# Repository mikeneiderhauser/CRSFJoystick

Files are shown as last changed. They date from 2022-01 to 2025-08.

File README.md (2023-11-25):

# ELRSJoystick / CRSFJoystick

<https://github.com/mikeneiderhauser/CRSFJoystick>

Named CRSFJoystick as it indicates the wire protocol between the microcontroller (pi pico) and receiver).

Arduino code using the mbed core that runs on a Pi Pico (2040) to emulate a USB HID Joystick

Pirmarily developed to use and ExpressLRS receiver and a HID Joystick for Sim use! It will work with both Tracer and Crossfire as well.

Shout out to CapnBry for the Crsf Library

https://github.com/CapnBry/CRServoF

Shout out to RealRobots.net for the Gamepad Library

https://gitlab.com/realrobots/PicoGamepad/-/tree/master

# Future Plans

- GitHub Builds
- Rework HID USB code
- Add failsafe nopulses / hold

# Demo Video
ELRS HID Joystick Demo (https://www.youtube.com/watch?v=MCOWKvFTHRc)

## Purchase

Originally offered of FPVExchange, but that is no longer an option. Please send me an email for availability, purchase, or to get additional info!

<housefpv@gmail.com>

You can also contact me on discord [HouseFPV](https://discordapp.com/users/HouseFPV#5899)

- Blank carrier boards for Pi Pico, Tiny 2040, and Waveshare RP2040 (old stock)
- Built and flashed units
- [DIY Section](#diy-hardware)

A few boards that I believe are based off of this project:
- HGLRC Dongle (I have samples from HGLRC on the way)
  - [HGLRC Dongle at HGLRC](https://www.hglrc.com/collections/new-arrivals/products/hglrc-c1-remote-control)
  - [HGLRC C1 Radio Kit with dongle at HGLRC](https://www.hglrc.com/collections/new-arrivals/products/hglrc-c1-remote-control)
  - [HGLRC C1 Radio Kit with dongle at RacedayQuads](https://www.racedayquads.com/products/hglrc-c1-transmitter-elrs-2-4ghz-choose-your-version?keyword=hglrc%20c1)
- Squid Stick (I have personally not tested one)
  -  [Squid Stick at Progressiverc.com](https://www.progressiverc.com/products/squid-stick-elrs-2-4ghz-usb-receiver-module)
  -  Squid Stick at RacedayQuads - Link to be posted when available
- YMZFPV Simulator Adapter (have not yet been able to confirm that this is based off of this project)
  - [YMZFPV Sim Adapter at RacedayQuads](https://www.racedayquads.com/products/ymzfpv-wireless-simulator-adapter-for-sbus-pwm-csfr-choose-your-version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)

## Compatability

This project was designed primarily with ELRS usage in mind, however this code base has also been tested with TBS Crossfire Receivers (915MHZ) (last tested v6.16) and TBS Tracer Receivers (2.4GHz) (last tested v6.17) and both appear to work! Flight was teseted in the Liftoff simulator.

I no longer have TBS Crossfire nor TBS Tracer TX modules or Receivers so future tests will have to be conducted by others.

### ExpressLRS (Waveshare RP2040)
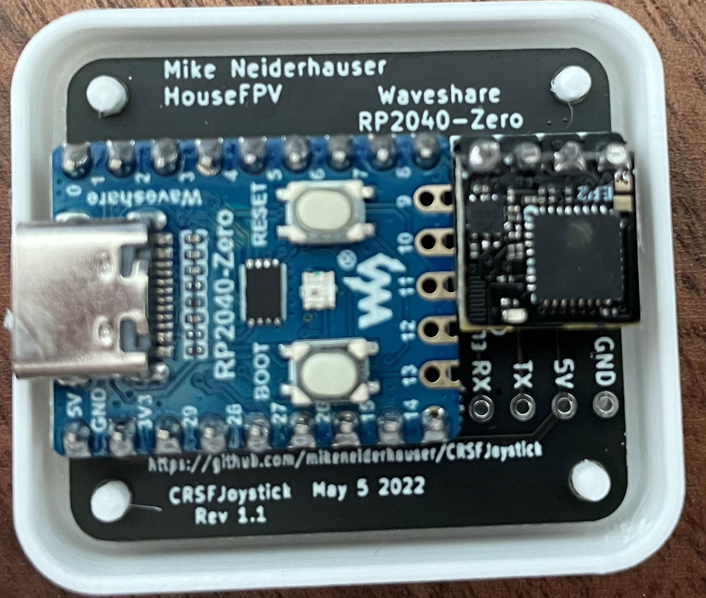
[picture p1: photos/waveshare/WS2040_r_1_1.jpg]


### Crossfire



### Tracer


# Building / Flashing

I recently converted the projet to PlatformIO to aid in building, board management, etc.  PlatformIO has some known quirks with PiPico boards and I'm going to leave some breadcrumbs here for later.

## VSCode with PlatformIO

### Installing VSCode and PlatformIO
<https://platformio.org/install/ide?install=vscode>

### Build for specific board / environment

At the Bottom of VSCode you will see a tool bar.  Look for `Default (CRSFJoystick)`.  Building in this state will build for all boards / environments defined in the `platformio.ini` file.  To target a sepecific board, Click on `Default (CRSFJoystick)` and select an appropriate option (Note, selection pops up at the top of vscode).



Click on the Checkmark on the bottom toolbar to build for the board / environment you selected.

Click on the `->` on the bottom toolbar to upload to the board.  If upload fails to find your board, please see bothe the [alternative upload](#alternative-upload) section as well as the driver section.

## Alternative upload
This is one of the standard advertised methods for uploading firmware to a pipico based microcontroller board.

Press and hold the bootsel button on your board and either plugin/power on the board or if the board is already powered press and release the reset button.

This will put the board in RP2 Boot mode.

A removable device should pop up or become available on your computer.  Drag and drop the `firmware.u2f` file from the `.pio/build/wavesharerp2040zero/` directory into this device on your computer.  Note replpace wavesharerp2040zero with the environment for your board.

## Drivers
Drivers can be hit or miss for the pipico board and platformio.  

You may need to use zadig to get vscode+platforio to be able to upload directly to the board.
<https://github.com/platformio/platform-raspberrypi/issues/2#issuecomment-828586398>

Below are the drivers I have working on my Windows 11 machine.  You may need to modify the driver selection via zadig and or device manager to get it working.

- Standard Running Mode
  - RaspberryPi Pico (Interface 0)
    - Zadig -> HidUsb v10.0.22621.819
    - Device Manager -> Human Interface Devices -> HID-compliant game controller
  - RaspberryPi Pico (Interface 1)
      - Zadig -> usbser v10.0.22621.1778
      - Device Manager -> Ports (COM & LPT) -> USB Serial Device
- RP2 Boot mode
  - RP2 Boot (Interface 0) 
    - Zadig USBSTOR v10.0.022621.1778 
    - Device Manager -> Disk Drives -> RPI RP2 USB Device 
  - RP2 Boot (Interface 1)
    - Zadig WinUSB v6.1.7600.16385
    Device Manager -> Universal Serial Bus Devices -> RP2 Boot

### Device manager clicks to change driver 
Right Click -> Properties -> Update Driver -> Browse my computer for drivers -> Let me pick from a list of available drivers on my computer

# Flashing ELRS Receiver

Depending on the device you are using, your target may be different.  For all of the DIY version's I've made, I used the HappyModel EP2 Rx.  Other vendors may vary.

## Flashing via Betaflight Passthrough
<https://www.expresslrs.org/software/updating/betaflight-passthrough/>

## Flashing via Wifi
If your receiver is wifi enabled you can also flash it via wifi

<https://www.expresslrs.org/software/updating/wifi-updating/>

# Testing
For a quick test of functionality, I typically go to [GamepadTester](https://hardwaretester.com/gamepad).

Once the Radio is bound to the RX, it should show up in GamePadTester.

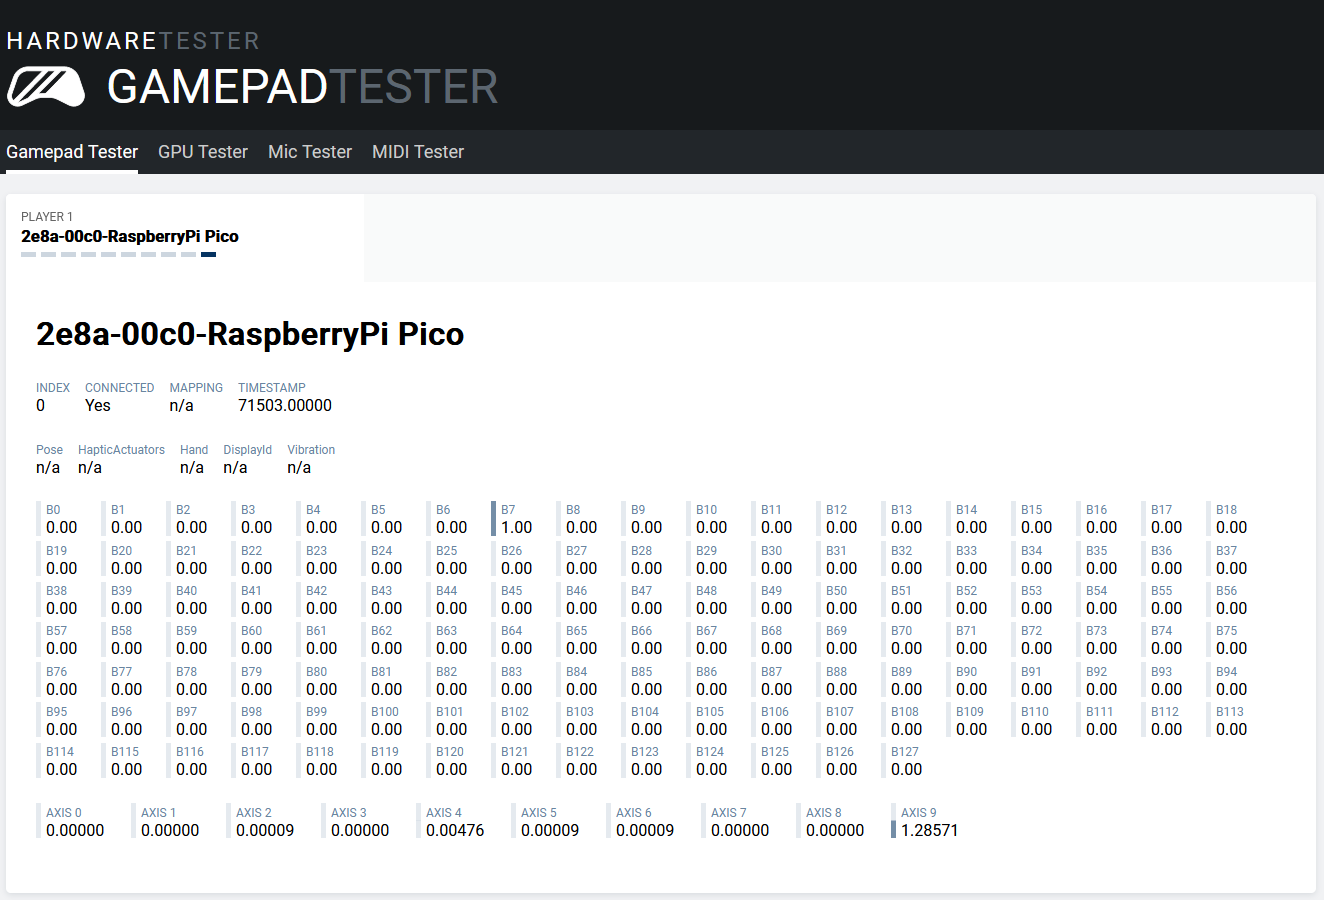
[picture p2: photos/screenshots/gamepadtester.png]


# Mappings
This was a quick map and is not fully featured.

On link up/down the onboard Pi Pico LED will light indicating connection

*NOTE* Channel 5, 6, 7, and 8 are mapped both to analog axis as well as joystick buttons.

| Channel | Logical Mapping  | Joystick Mapping |
| --- | --- | --- |
| 1 | A | X |
| 2 | E | Y |
| 3 | T | Rx |
| 4 | R | Ry |
| 5 | Channel 5 (Full) AND AUX1 (1510-2011) | Z  AND Button 0 |
| 6 | Channel 6 (Full) AND AUX2 (1510-2011) | Rz AND Button 1 |
| 7 | Channel 7 (Full) AND AUX3 (1510-2011) | S0 AND Button 2 |
| 8 | Channel 8 (Full) AND AUX4 (1510-2001) | S1 AND Button 3 |
| 9 | AUX5 (1510-2011) | Button 4 |
| 10 | AUX6 (1510-2011) | Button 5 |
| 11 | AUX7 (1510-2011) | Button 6 |
| 12 | AUX8 (1510-2011) | Button 7 |
| 13 | Not Used | Not Used |
| 14 | Not Used | Not Used |
| 15 | LQ - Not Used | Not Used |
| 16 | RSSI - Not Used  | Not Used |

*Note additional button mappings can be created in caliration.h*

# Here below is for DIY Builds and may be slightly outdated
# DIY Hardware

In a nutshell, wire the ELRS RX up to a uart on the pipico, 5v, and gnd.

| Raspberry Pico | ELRS/CRSF Receiver |
| --- | --- |
| VBUS (PIN 40)  | 5V |
| GND  (PIN 38)  | GND
| GP4  (PIN 6) | RX |
| GP5  (PIN 7) | TX |

Other boards are supported, see the [board_defs.h](./include/board_defs.h) file.

| Part  | Link | Approx Cost |
| ----- | ---- | ---|
| Pi Pico | https://www.pishop.us/product/raspberry-pi-pico/ | $4 (Approx $6 with shipping) |
| Waveshare RP2040 zero | https://www.amazon.com/RP2040-Zero-Development-Microcontroller-Multi-Function-Integration/dp/B09SBCKYSC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| $10|
| Tiny 2040 (alt part) | https://www.pishop.us/product/tiny-2040/ | $10 (Approx $12 with shipping) |
| ELRS RX (any will do) |  https://www.racedayquads.com/products/happymodel-2-4ghz-ep2-tcxo-rx-express-lrs-receiver?keyword=expresslrs | $18 |

Note, price breaks can be had when purchasing at quantity.

Approx part cost for pico hardware (large footprint, cheaper) - $20-$25

- Pi Pico - $4.00
- ELRS RX - $13.50 
- Carrier Board - $1.00 (approx)
- Shipping / Tax from vendors - varies

# Carrier Boards

## ELRSJoystick

This board has an ELRS RX built in, so you don't need to wire any RX on, just plug in and connect to your ELRS TX, then you are ready to go!

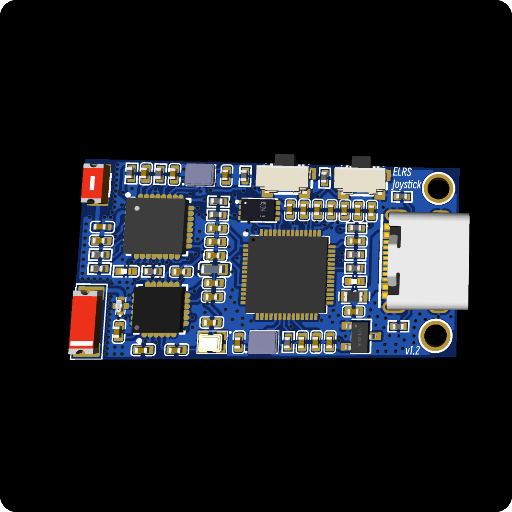
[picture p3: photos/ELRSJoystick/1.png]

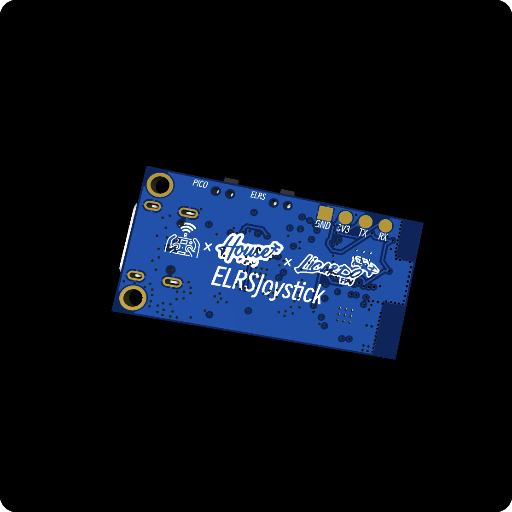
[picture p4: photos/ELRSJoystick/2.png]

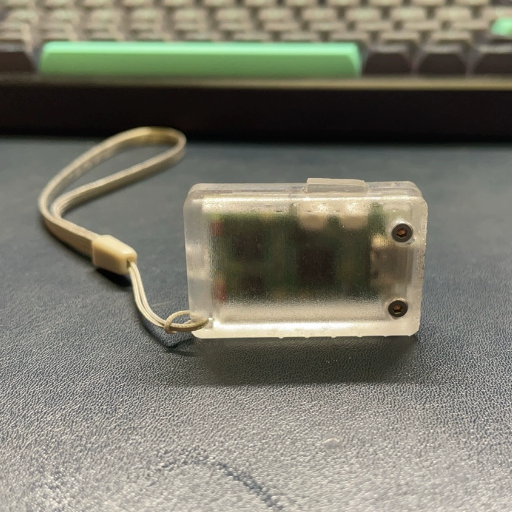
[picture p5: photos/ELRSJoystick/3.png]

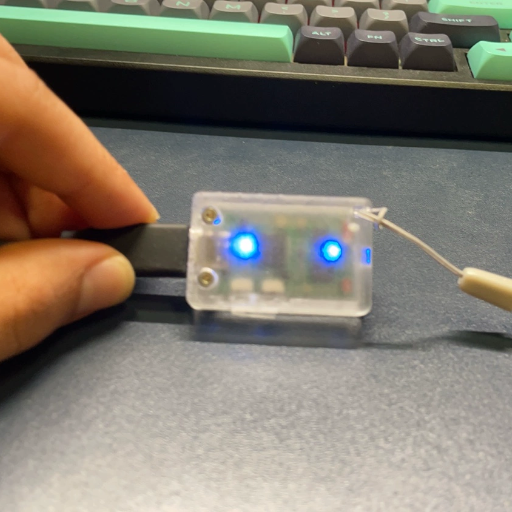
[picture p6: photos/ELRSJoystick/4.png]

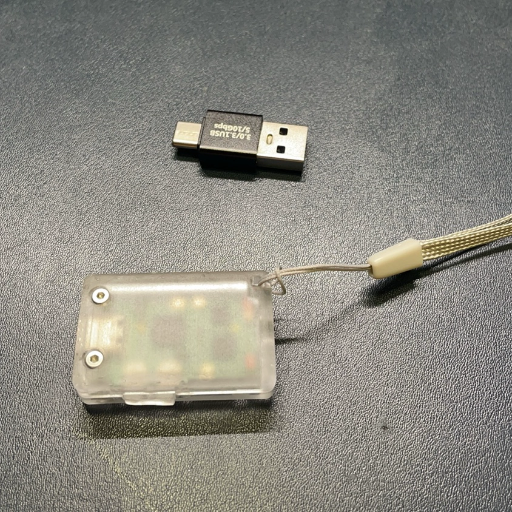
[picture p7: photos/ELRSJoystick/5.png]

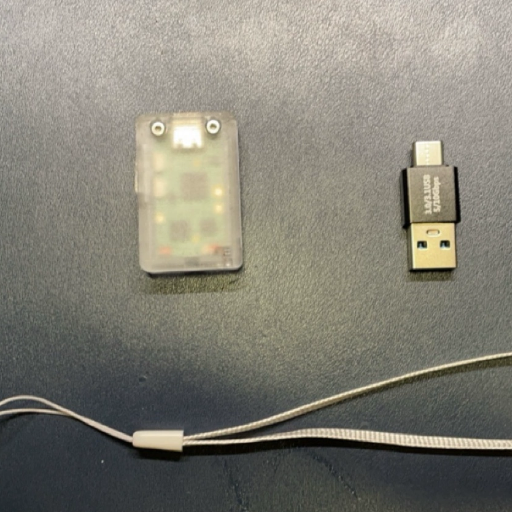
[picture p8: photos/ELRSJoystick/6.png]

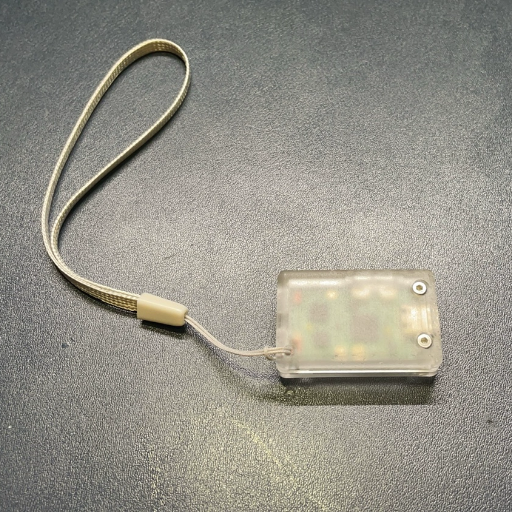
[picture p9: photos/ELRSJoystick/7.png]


## Tiny Version

> **_NOTE:_** References to level shifters below are no longer needed as the level shifter can be omitted. You will have to bridge the pads on the level shifter for the TX/RX pins or use a newer version of the carrier board.

I personally use the Waveshare RP2040-Zero version for my ELRS Joystick!

Hardware build files are located in hardware/kicad/CRSFJoystick/output/Rev1.0

I used JLCPCB with Black Soldermask and a board thickness of 1.6mm.

R1.0 Build Photo

Note the different orientation of the ELRS RX's.  The orientation can be flipped.  I installed each RX to ensure the boot pad is exposed should the RX need recovered.

## Waveshare RP2040-Zero

[WaveShare RP2040-Zero Board](https://www.waveshare.com/rp2040-zero.htm)

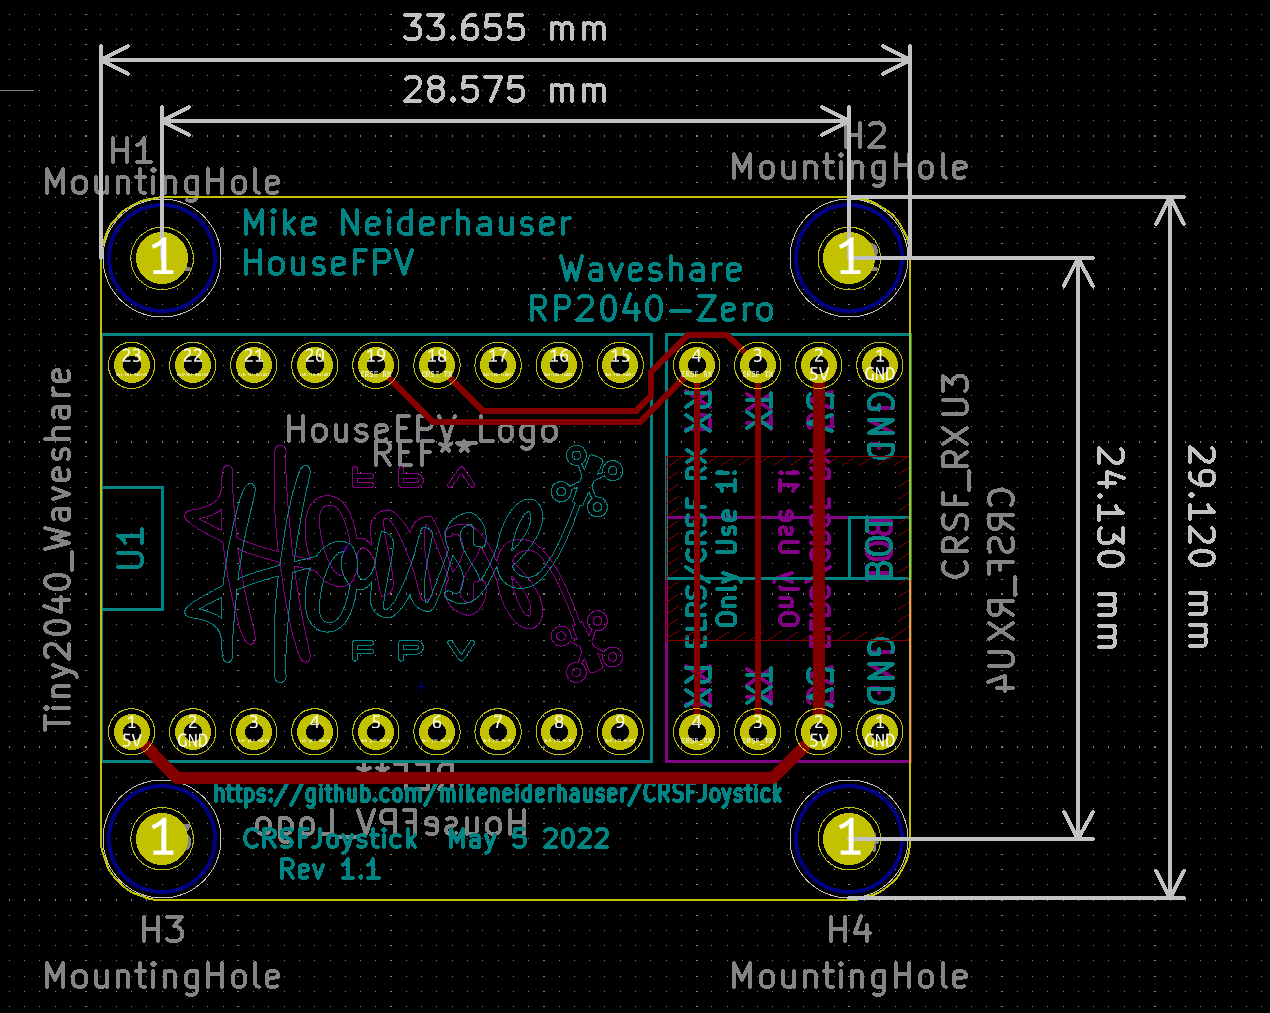
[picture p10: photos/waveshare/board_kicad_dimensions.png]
WaveShare RP2040-Zero BoardDimensions


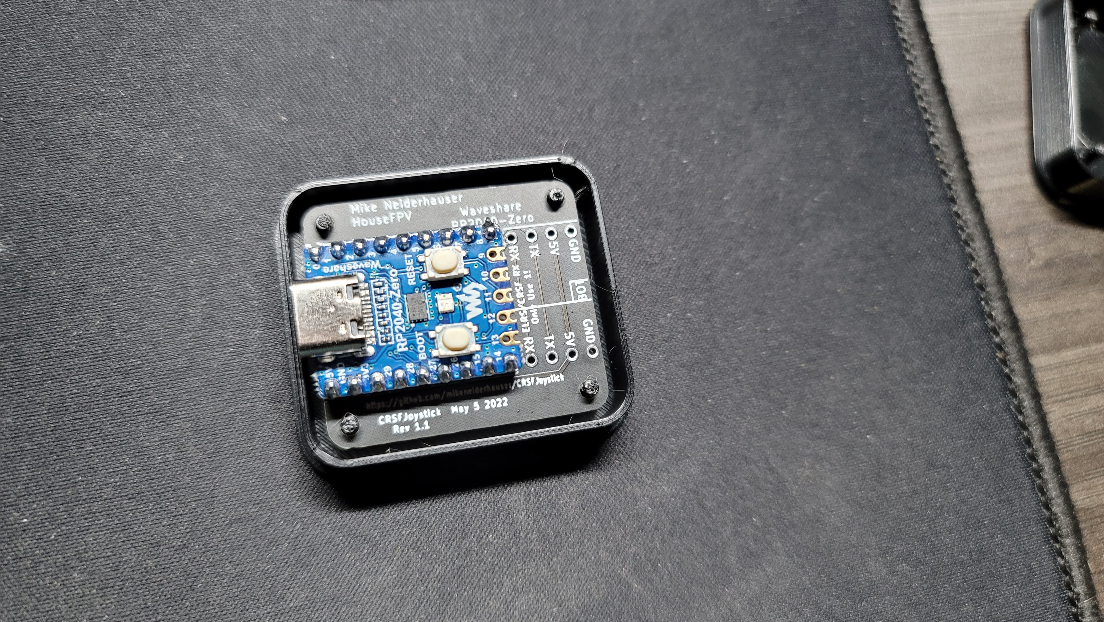
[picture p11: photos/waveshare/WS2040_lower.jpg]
WaveShare RP2040 Case lower


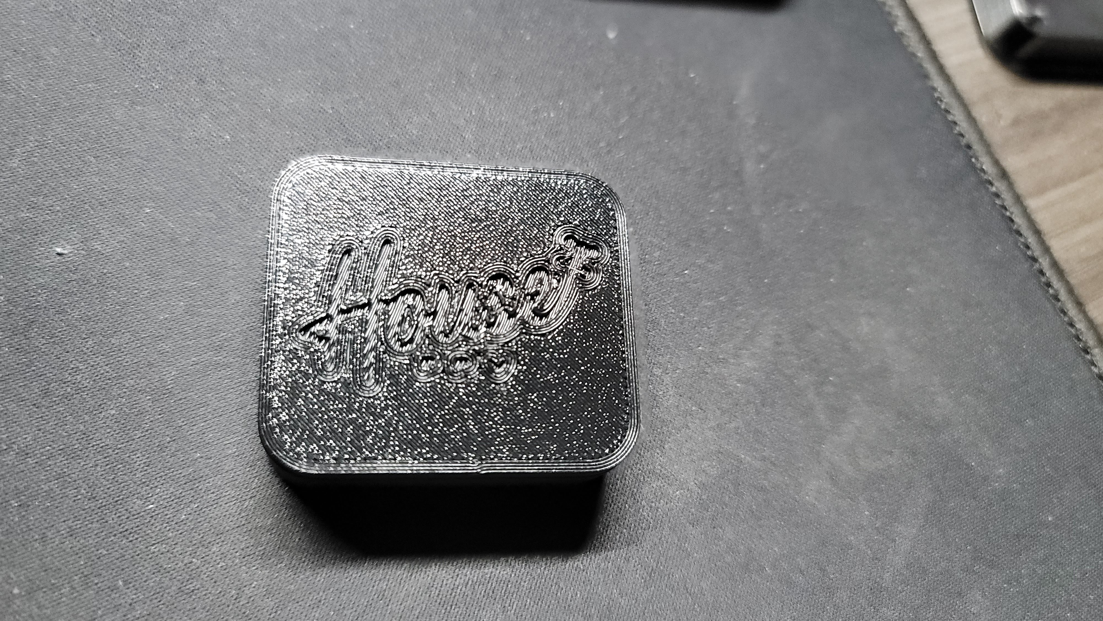
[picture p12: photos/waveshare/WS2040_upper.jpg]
WaveShare RP2040 Case Upper


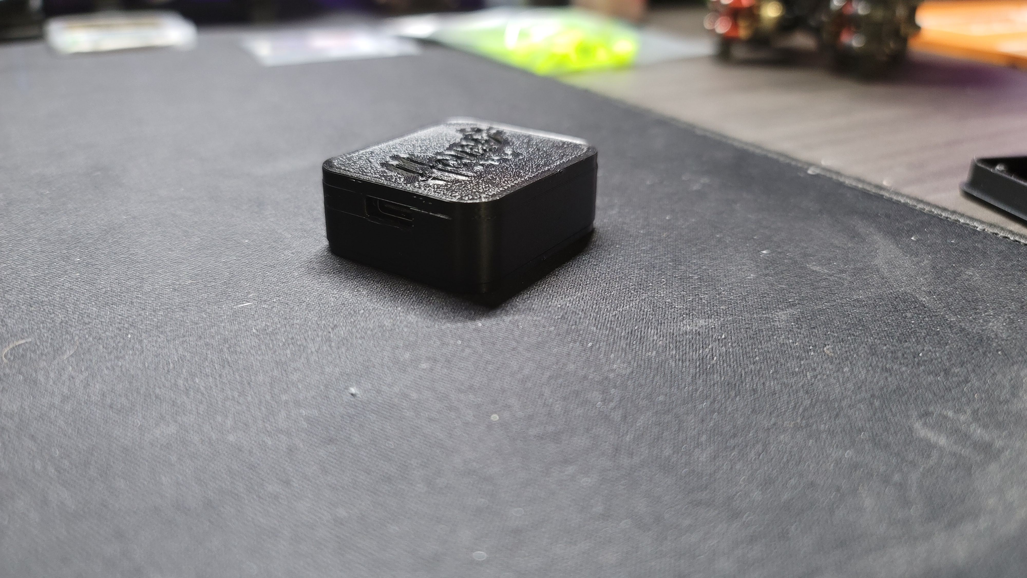
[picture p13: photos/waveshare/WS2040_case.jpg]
WaveShare RP2040 Case assembled


## Raspberry Pi Pico (Full Version)

Pico Build Front

Pico Build Back

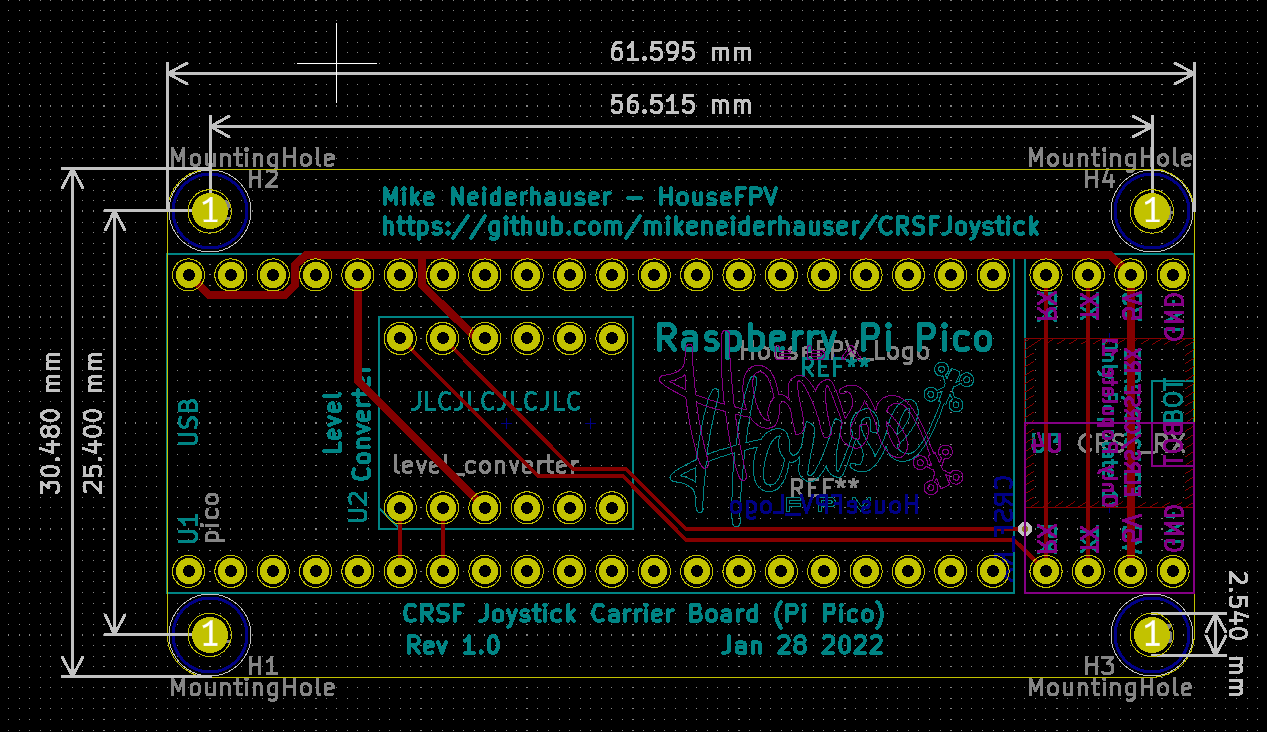
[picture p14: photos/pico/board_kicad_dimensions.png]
Pi Pico Dimensions


## Tiny2040

Tiny2040 Build Front

Tiny2040 Build Back

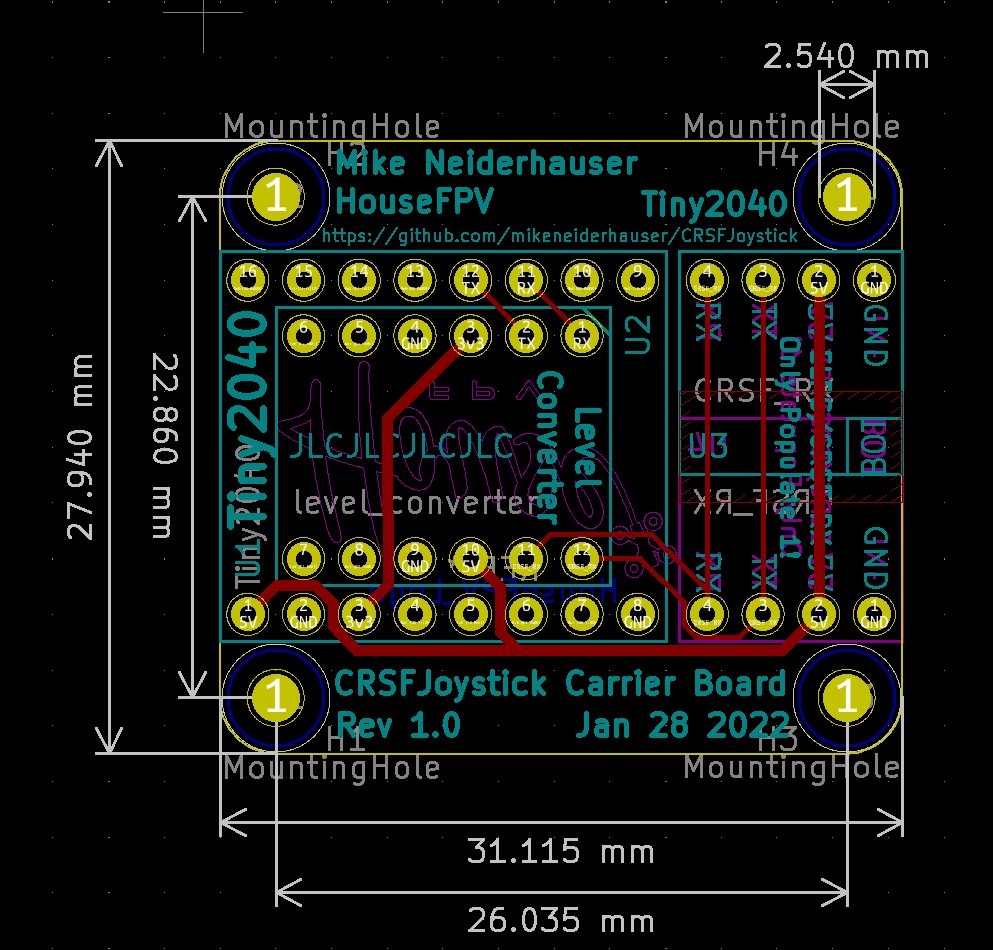
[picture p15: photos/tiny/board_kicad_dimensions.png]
Tiny2040 Dimensions


## SEEED AXIO 2040

Board files now in the hardware folder.  Not built or tested but should work.

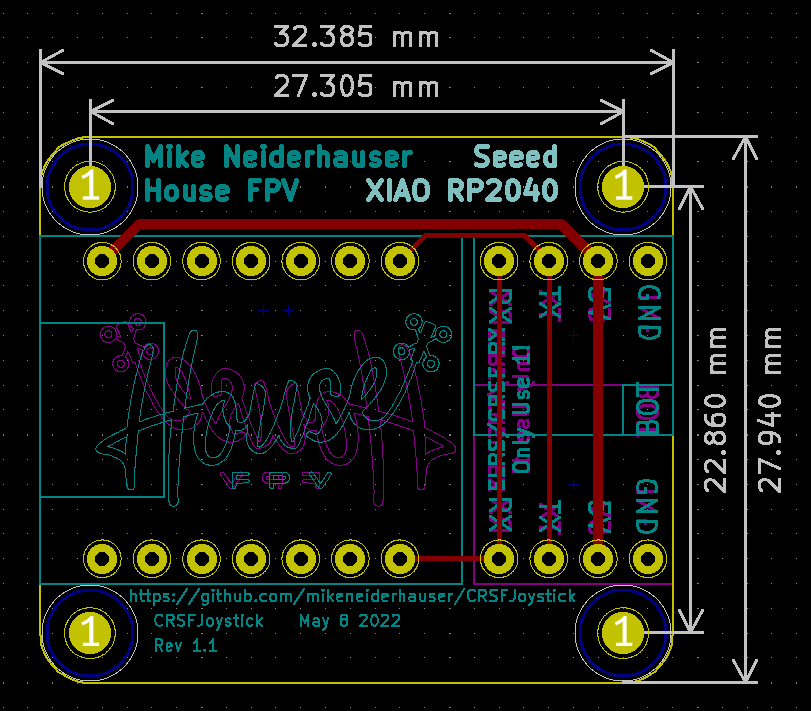
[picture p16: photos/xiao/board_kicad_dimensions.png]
SEEED XAIO RP2040 Dimensions


[SEEED XAIO RP2040 Board](https://www.seeedstudio.com/XIAO-RP2040-v1-0-p-5026.html)

## CRSFJoystick2.0

Build a smaller pico by yourself.

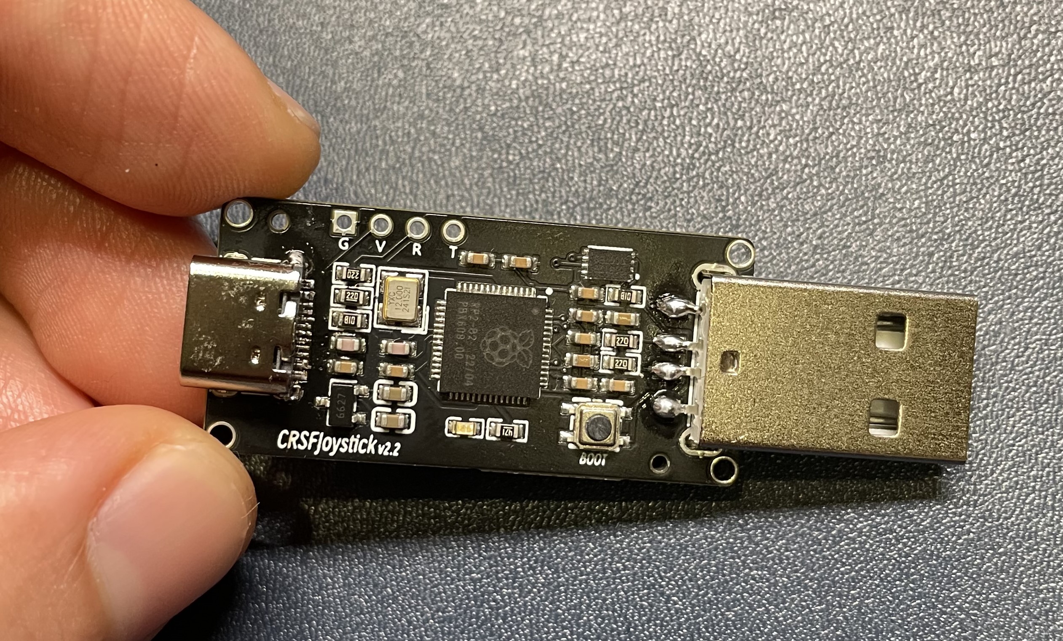
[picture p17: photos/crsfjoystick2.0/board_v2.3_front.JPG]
CRSFJoystick2.3 Board Front

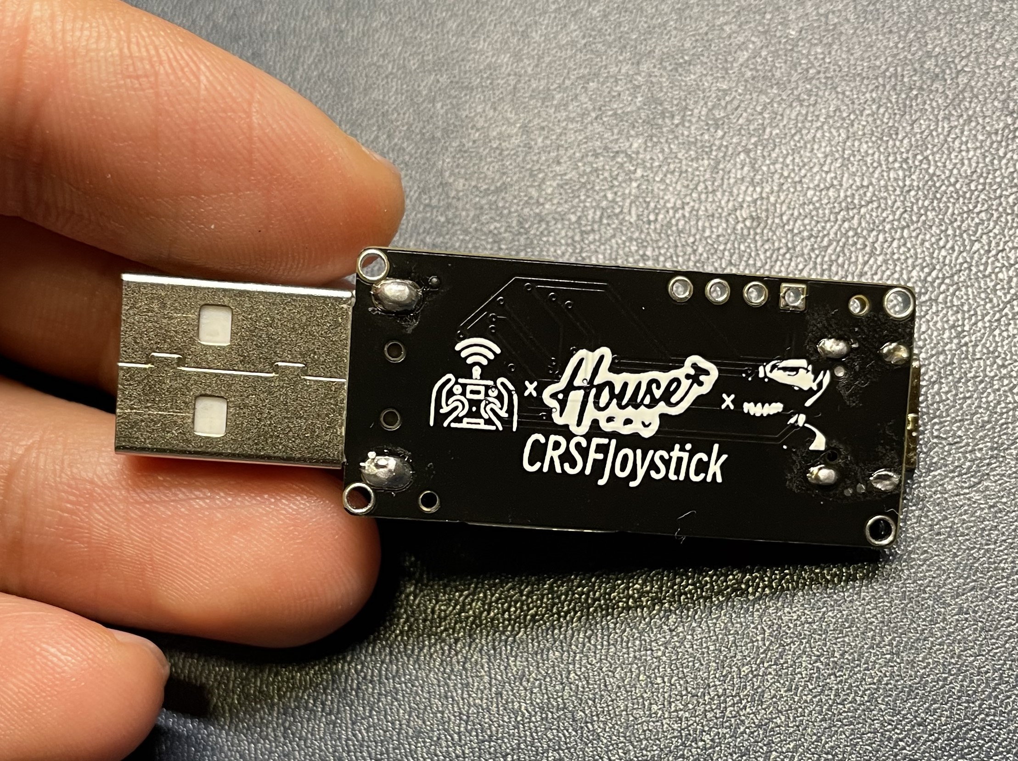
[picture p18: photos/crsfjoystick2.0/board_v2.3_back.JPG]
CRSFJoystick2.3 Board Back

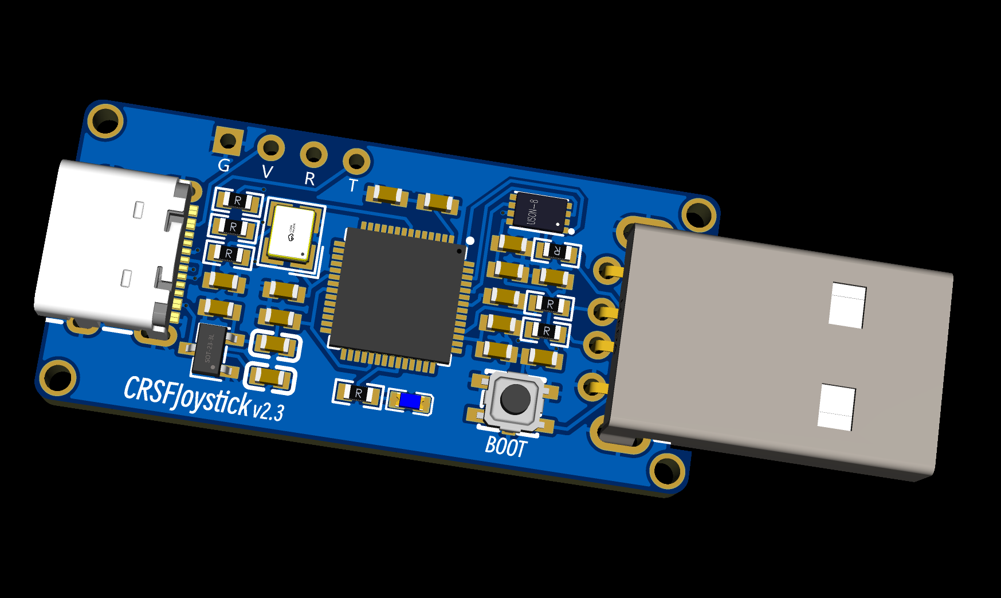
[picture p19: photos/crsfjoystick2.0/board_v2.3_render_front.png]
CRSFJoystick2.3 Render Front

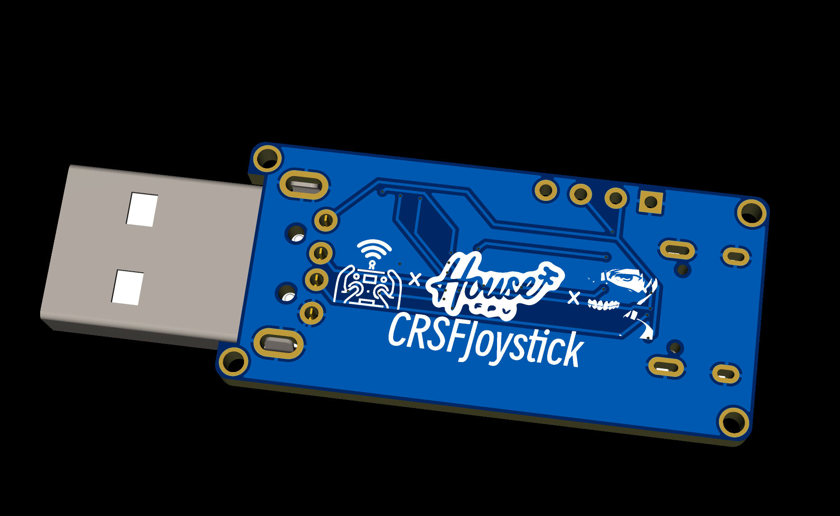
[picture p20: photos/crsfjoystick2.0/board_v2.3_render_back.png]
CRSFJoystick2.3 Render Back

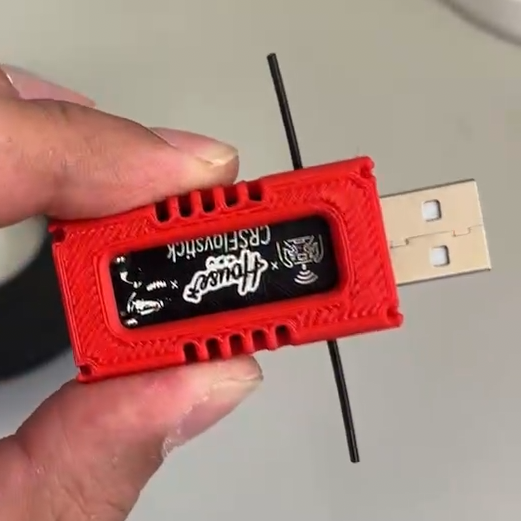
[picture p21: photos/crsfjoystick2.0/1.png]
CRSFJoystick2.3 Render Back

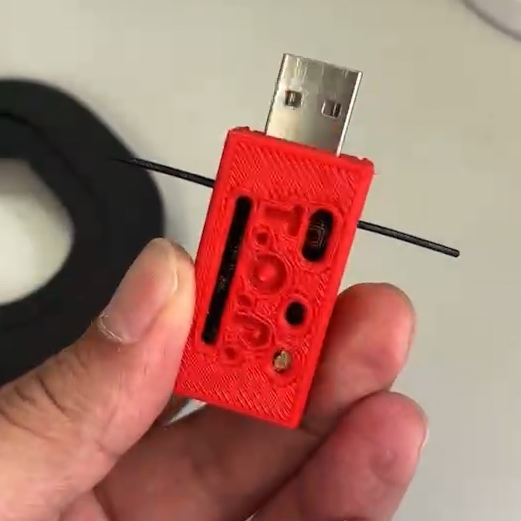
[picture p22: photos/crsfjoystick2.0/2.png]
CRSFJoystick2.3 Render Back

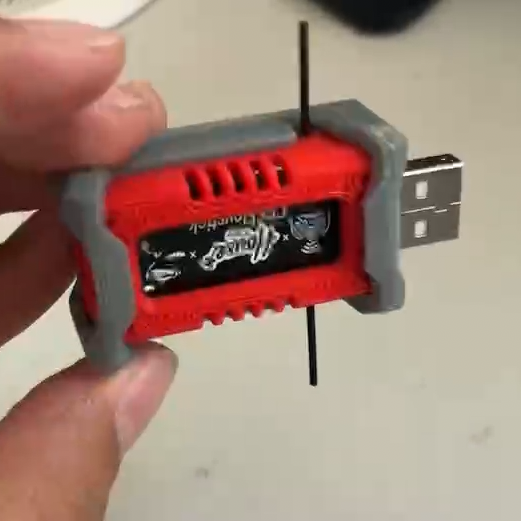
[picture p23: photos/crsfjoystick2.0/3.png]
CRSFJoystick2.3 Render Back

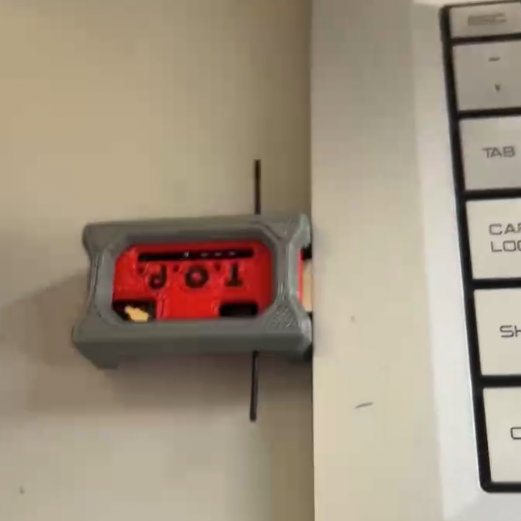
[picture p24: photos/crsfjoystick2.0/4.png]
CRSFJoystick2.3 Render Back

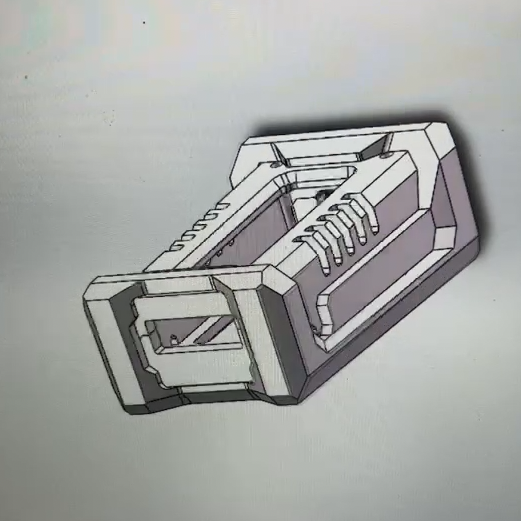
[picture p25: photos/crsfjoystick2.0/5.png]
CRSFJoystick2.3 Render Back

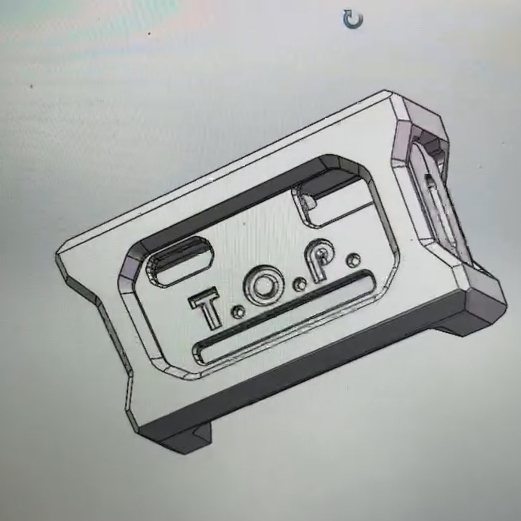
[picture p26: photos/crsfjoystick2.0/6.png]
CRSFJoystick2.3 Render Back

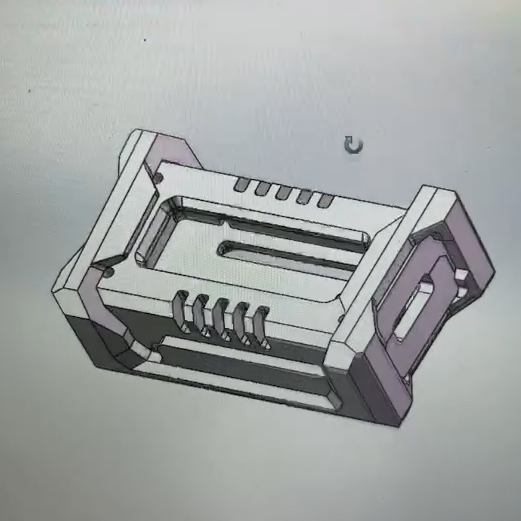
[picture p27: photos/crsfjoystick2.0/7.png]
CRSFJoystick2.3 Render Back


# General Assembly

- Print the top and bottom enclosure
- Print 2 of the spacers for the Pi2040, Print 4 of the spacers for the Pi Pico version
- Follow the directions in this video https://youtu.be/Zuhfbobgm5A

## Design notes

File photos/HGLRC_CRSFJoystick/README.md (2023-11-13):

Onboard 2.4GHz ELRS receiver, receiver firmware: HGLRC Hermes 2.4GHz RX.   
Reserve the expansion receiver pad and use the toggle switch to switch between the onboard or external receiver.   
The latest uploaded Gerber file adds the housefpv and ExpressLRS logos.

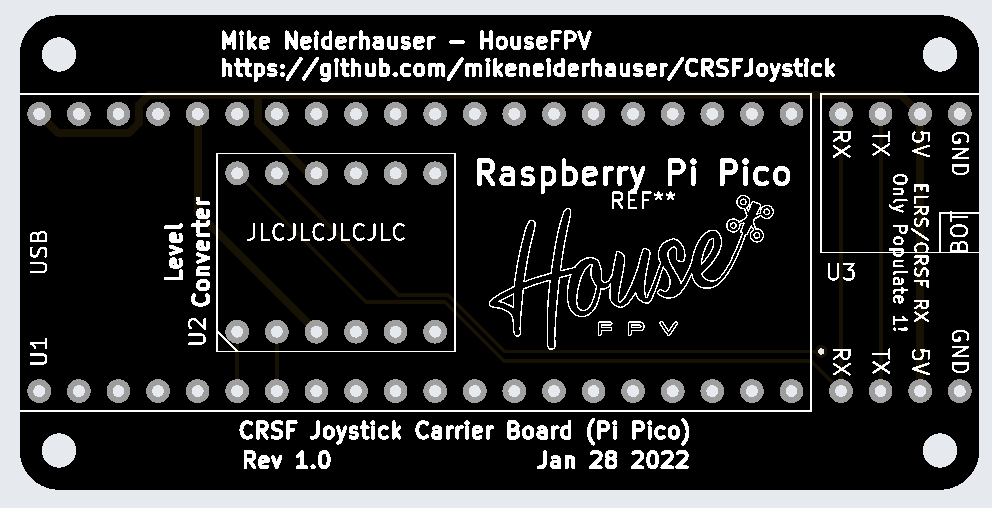
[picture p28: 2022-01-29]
photos/pico/board_render_front.png

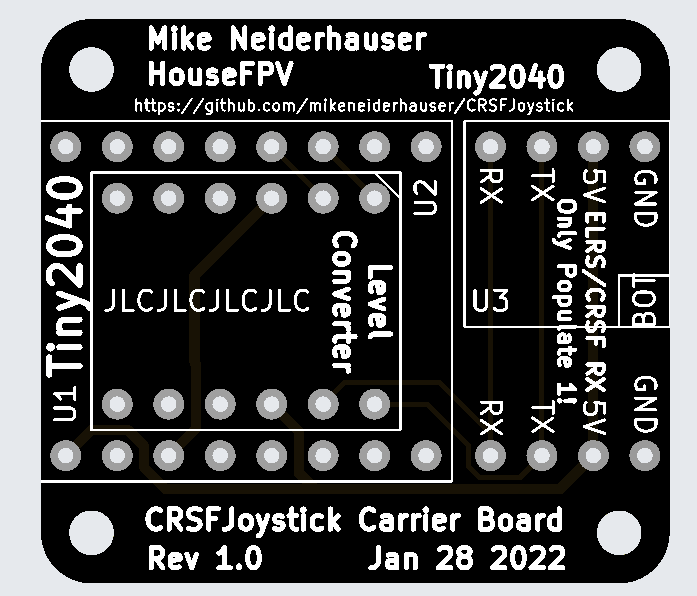
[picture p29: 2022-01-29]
photos/tiny/board_render_front.png

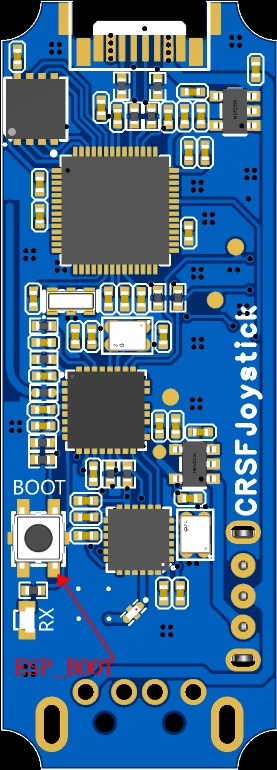
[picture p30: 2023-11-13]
photos/HGLRC_CRSFJoystick/board_render_back_V1.1.jpg

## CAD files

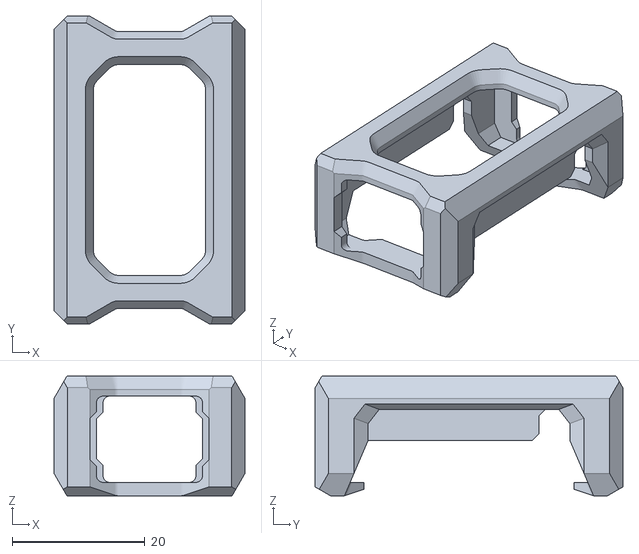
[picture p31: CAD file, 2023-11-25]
STL/CRSFJoystick/v2.3/Cover.STL
28.8 x 46.4 x 18.0

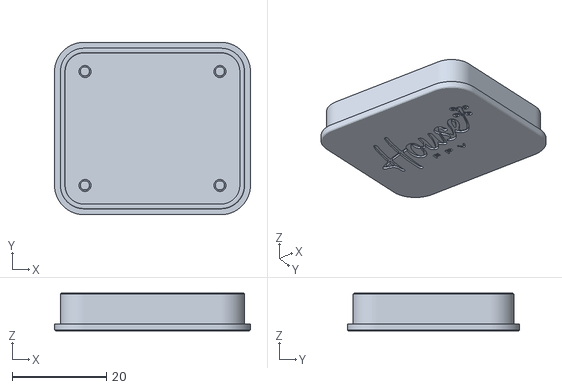
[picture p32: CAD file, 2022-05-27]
STL/CRSFJoystick/Waveshare_2040/Waveshare RP2040 Lower.stl
41.5 x 36.5 x 8.00

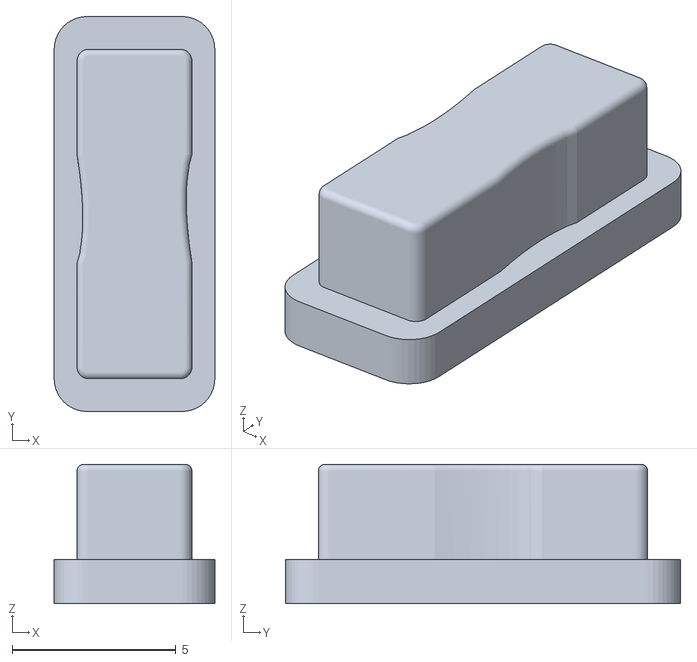
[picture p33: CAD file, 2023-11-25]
STL/ELRSJoystick/Licardo/Button.stl
4.90 x 12.0 x 4.25

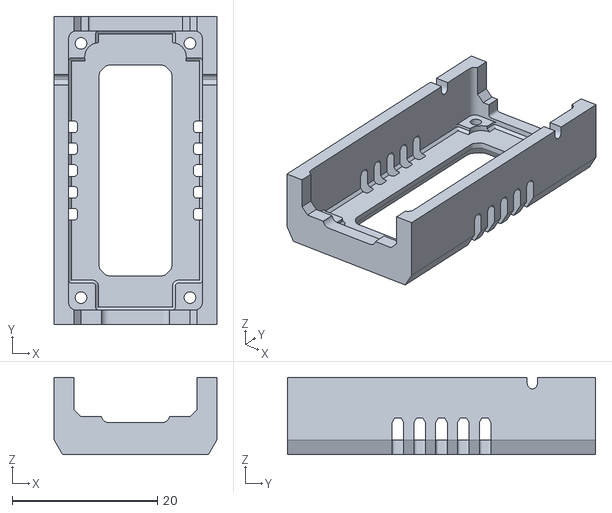
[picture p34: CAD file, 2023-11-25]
STL/CRSFJoystick/v2.3/Bottom.STL
22.4 x 42.4 x 10.6

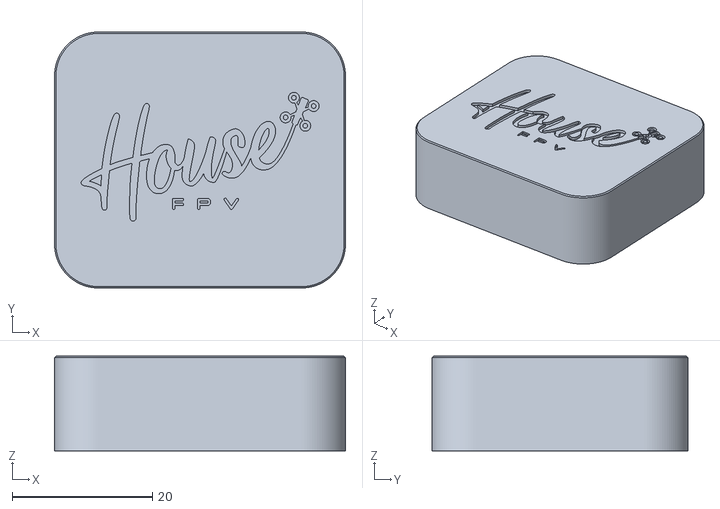
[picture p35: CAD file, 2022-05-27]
STL/CRSFJoystick/Waveshare_2040/Waveshare PR2040 top.stl
41.5 x 36.5 x 13.5

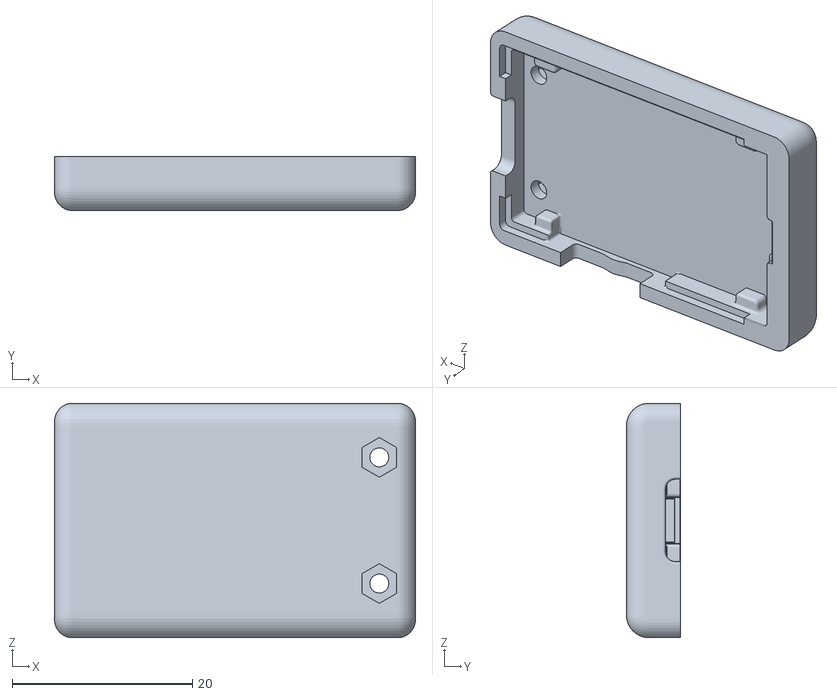
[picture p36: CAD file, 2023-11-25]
STL/ELRSJoystick/Licardo/Bottom.STL
40.0 x 6.00 x 26.0

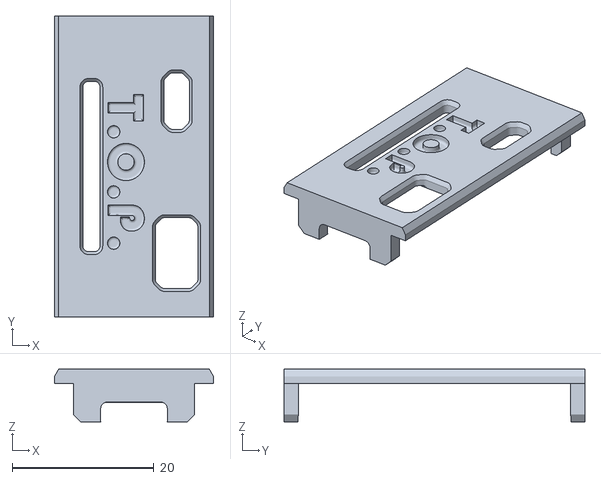
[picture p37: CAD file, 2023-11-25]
STL/CRSFJoystick/v2.3/Top.STL
22.4 x 42.4 x 7.40

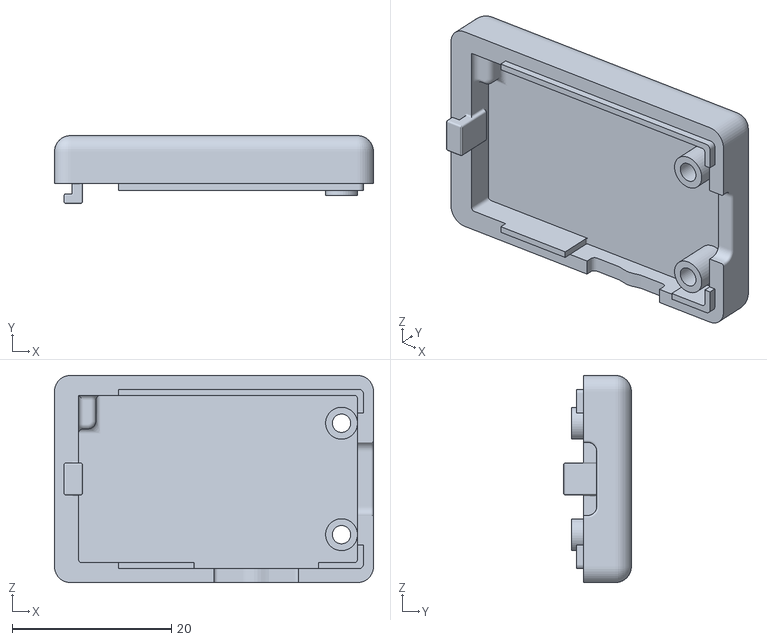
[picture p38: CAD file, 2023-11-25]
STL/ELRSJoystick/Licardo/Top.STL
40.0 x 8.50 x 26.0

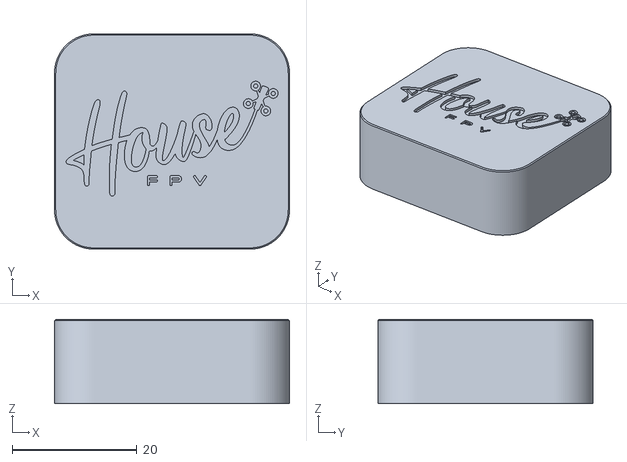
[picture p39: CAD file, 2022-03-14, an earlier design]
STL/CRSFJoystick/v1.0/top.stl
37.6 x 34.4 x 13.5

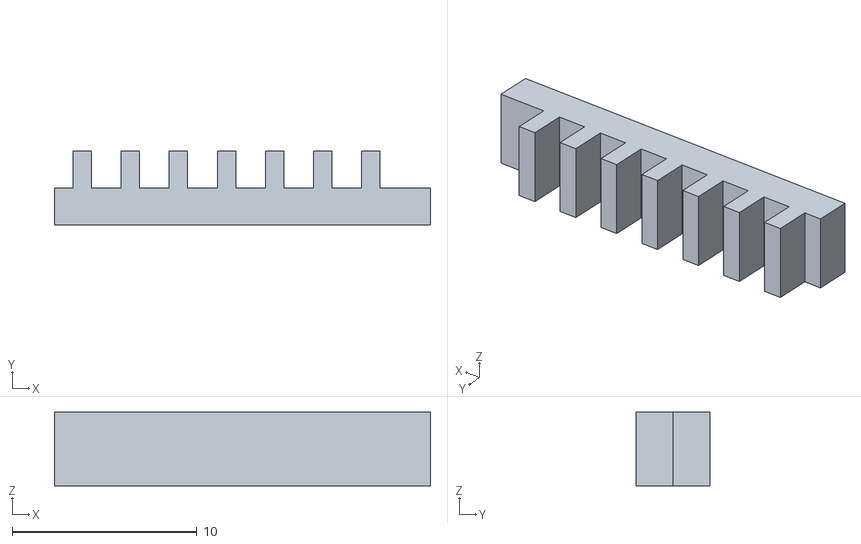
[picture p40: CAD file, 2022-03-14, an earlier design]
STL/CRSFJoystick/v1.0/spacer.stl
20.4 x 4.00 x 4.00

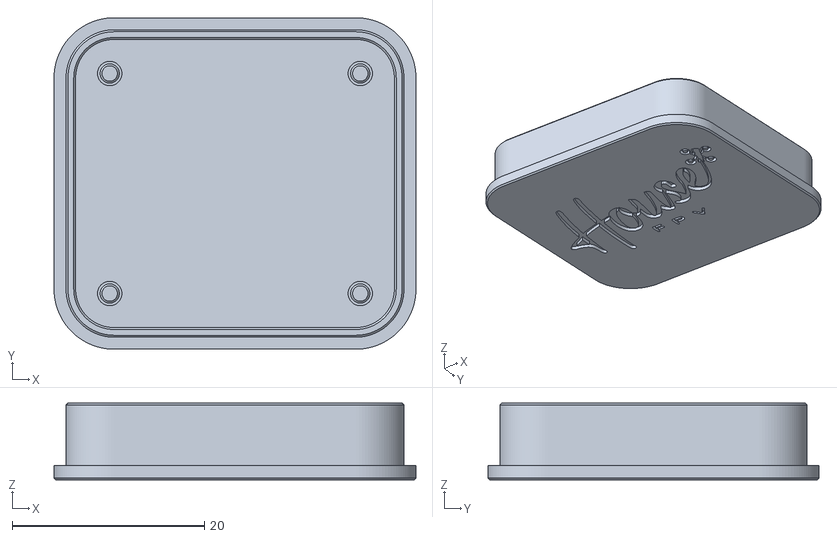
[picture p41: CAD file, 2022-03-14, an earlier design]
STL/CRSFJoystick/v1.0/Lower.stl
37.6 x 34.4 x 8.00

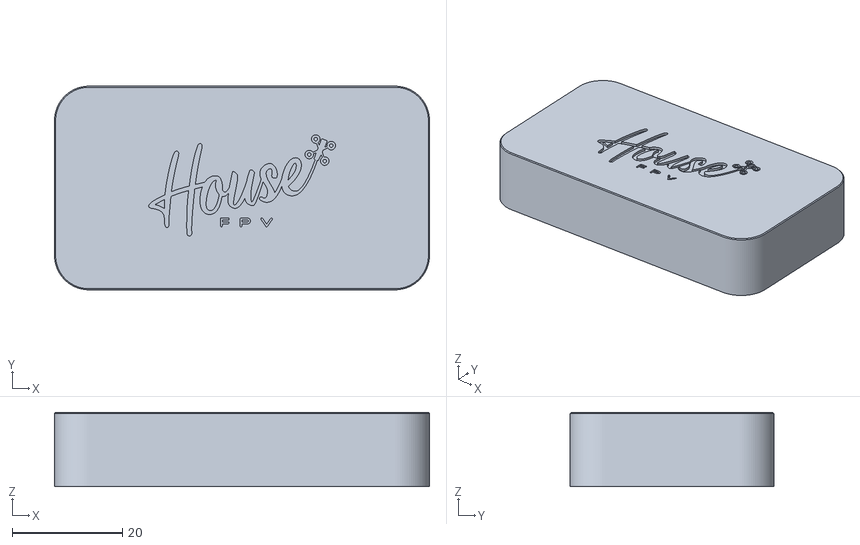
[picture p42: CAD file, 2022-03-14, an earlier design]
STL/CRSFJoystick/v1.0/pico top.stl
68.1 x 37.0 x 13.5

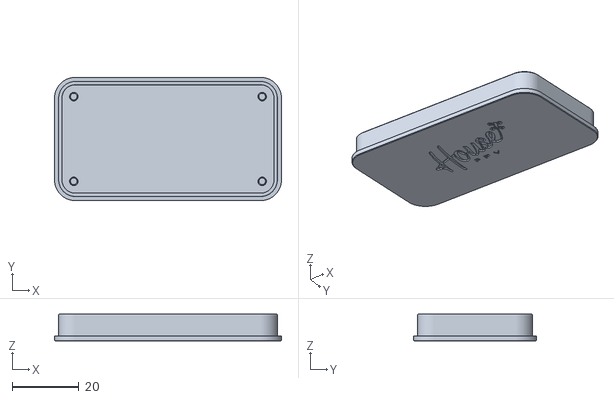
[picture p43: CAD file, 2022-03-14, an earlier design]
STL/CRSFJoystick/v1.0/Pico Lower.stl
68.1 x 37.0 x 8.00

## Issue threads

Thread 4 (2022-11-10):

PCB file does not include v1.1

L1cardo, 2022-11-10:
Hi, the pcb file you privided does not include 1.1 version. Can you upload them please?
Thanks!
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

mikeneiderhauser, 2022-11-13:
Please check here.  Not the pcb files, but a gerber bundle you can directly upload to fab
https://github.com/mikeneiderhauser/CRSFJoystick/tree/master/hardware/kicad/CRSFJoystick/output/Rev1.1

L1cardo, 2022-11-13:
I know this.
In China, there is a PCB manufacturer where you can get PCBs for free only if you have the origin files.

Closed 2022-11-29.

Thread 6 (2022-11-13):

pitch not working on ubuntu

kenken64, 2022-11-13:
axis 0 not working when i push the pitch forward it stays on 0 , after calibrate also useless

mikeneiderhauser, 2022-11-13:
I've tested this on ubuntu.  Can you please provide more info?
What MCU are you using?
Did you make boards?
Did you modify the pi pico code, if so, what were the modifications?
ELRS Version?
Ubuntu Version?

Closed 2022-12-02.

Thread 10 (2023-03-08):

Update ELRS firmware

benedikt-bartscher, 2023-03-08:
Hey @mikeneiderhauser, thanks you for your awesome work! Is there a way to update the ELRS receiver firmware? Or is it currenty always in USB HID mode?

benedikt-bartscher, 2023-03-09:
Thanks for your answer. Sadly some ELRS receivers don't have wifi (868mhz ones).
Couldn't we just introduce a boot delay in which the user can press for example a button to start in FW update mode?
Betaflight allows updating elrs receivers with serial passtrough, i used it many times, works great. Did you try this https://docs.arduino.cc/built-in-examples/communication/SerialPassthrough ?

mikeneiderhauser, 2023-03-09:
You can't do just native serial pass through (at least on the ESP based RX's, haven't tried the STM based RX's) as the boot loader does dynamic baud rates for programming.  I've tried dedicated bridge / serial pass through firmware that is supposed to do dynamic baud without success.

countofkrakow, 2023-05-12:
Just submitted a PR for this

mikeneiderhauser, 2023-05-27:
PR merged, elrs passthrough flashing is now functional

Closed 2023-05-27.

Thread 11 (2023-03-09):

Add instructions for Seeed XIAO 2040

benedikt-bartscher, 2023-03-09:
Compiling with Arduino Mbed OS RP2040 Boards -> Raspberry PI pico works fine, but uploading fails.
I tried compiling with different board definitions for the Seeed 2040 but i always get this error while compiling:
```
/home/bb/dev/CRSFJoystick/Sketchbook/libraries/PicoGamepad/PicoGamepad.h:21:10: fatal error: PluggableUSBHID.h: No such file or directory
```

mikeneiderhauser, 2023-03-09:
IIRC you still target the Pi pico not the seeed 2040.  Change the define selection at the top of the sketch and it should just work (at least how i've done it in the past).

benedikt-bartscher, 2023-03-09:
Yes that's what i tried first, compilation works finde, but uploading always fails with this message (i tried in normal and bootloader mode):
```
Beim Hochladen des Sketches ist ein Fehler aufgetreten
```

However uploading an empty sketch via the Seeed XIAO target works fine.

sk8board, 2023-12-22:
I noticed the Seeed XIAO 2040 only has UART0 (Serial1) but the `main.cpp` file calls for Serial2 (UART1).

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

Is the problem from the incorrect UART being used for Seeed XIAO 2040?

Closed 2023-10-13.

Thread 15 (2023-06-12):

Fpv Exchange is down

erockman95, 2023-06-12:
It seems that fpvexchange.com is down. Is there another way to buy the carrier board and/or premade units?

mikeneiderhauser, 2023-06-17:
Yea, unfortunately it looks like FPVexchange is down for good.  Message me on discord (HouseFPV) and I'll see if I have anything left here in stock and we can get something working to send to you.

erockman95, 2023-06-28:
Hey Mike,

Sorry I missed your email. In the meantime I was able to find a
crsf joystick2.0 online and bought it. Only problem is, I'm having trouble
programming it. Any chance you'd be able to help a brotha out? Also, tried
finding you on discord, but for some reason I can't find anything. Do you
have a direct link or your usercode or something that'd I'd be able to use
to get in touch with you? Thanks again.

On Sat, Jun 17, 2023 at 10:07 AM Mike Neiderhauser ***@***.***>
wrote:

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

erockman95, 2023-06-28:
Nevermind, was making a dumb mistake. I got it. Preciate all the effort you guys put in to this project! I'll be on the look out in case you do anything else in the future. And I'd deff still want to join your discord, so if you can get me a way to join thatd be dope. Take it easy Mike

Closed 2023-06-19.

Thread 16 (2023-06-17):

Support for more buttons

relaxibus, 2023-06-17:
Hi, awesome project! Do you plan to add more buttons? Multiple buttons can be mapped on a single channel using different pwm values.

I made a XIAO carrier board, could this be added to your support? I‘m not a coder, but can send you a board.

mikeneiderhauser, 2023-06-17:
Hi Relaxibus, If you contact me on Discord (HouseFPV) we can work together to see what you want multiple buttons wise as well as getting your carrier board in for XIAO.

relaxibus, 2023-06-18:
Ok!

mikeneiderhauser, 2023-07-04:
Unfortunately button mapping isn't a one size fits all for everyone.  You can add more buttons to the map by modifying the configuration here

https://github.com/mikeneiderhauser/CRSFJoystick/blob/master/Sketchbook/CRSF_Joystick/calibration.h#L47

If you would like to propose some better defaults than the stock 8 buttons please let me know!

relaxibus, 2023-07-12:
ok, thanks :-)

Closed 2023-10-13.

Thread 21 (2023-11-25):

Add pin info in readme

RobertoD91, 2023-11-25:
Hi, thank you for this amazing work. It might be a good idea to add the default TX and RX pins in the README.

Something like
| Raspberry Pico      | CRSF Receiver |
| ----------- | ----------- |
| 4      | RX       |
| 5   | TX        |

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

mikeneiderhauser, 2023-11-25:
Added a pin section to the DIY hardware heading in the README.
https://github.com/mikeneiderhauser/CRSFJoystick#diy-hardware

Other pin defs can also be found in the board_defs.h file

Thanks for the feedback!

Closed 2023-11-25.

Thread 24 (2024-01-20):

Use library with Arduino RP2040 Connect

kingfisher09, 2024-01-20:
Hi,

I'm building a robot using an Arduino RP2040 Connect. I want to control the robot using ELRS. I've uploaded the basic_crsf example to the board, it compiles just fine but I'm not seeing a signal. I'm not sure whether I'm using the right RX and TX pins on the board.

I see in the code you can select Serial1 or Serial2 but I'm not sure what they refer to. The [Arduino pinout ](https://docs.arduino.cc/static/a4d65079ebe3058e37153eb0f93890a8/2f891/pinout.png)only lists one RX and TX so I tried that first but I also see that on the [Pi Pico pinout](https://cdn-learn.adafruit.com/assets/assets/000/099/339/original/raspberry_pi_Pico-R3-Pinout-narrow.png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) there are other pins for other serial ports so I tried connecting to the equivalents of those pins.

Is there something else that I'm missing?

Thanks

mikeneiderhauser, 2024-01-23:
Which board ID are you using?  Looking at the pinout, try board ID 4 (you may need to modify some things in board defs to disable the led functionality), and wire it up to TX and RX pins on the Arduino Nano Connect RP2040

mikeneiderhauser, 2024-11-01:
Closing due to inactivity

Closed 2024-11-01.

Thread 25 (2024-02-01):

New version of Velocidrone with disconecting issue with CRSFJoystick

eduardorcosta, 2024-02-01:
Hi, sorry to bother but, I donwload the lastest version of velocidrone, that I'm runing with Waveshare RP2040 and ELRS, but it now has some strange behaviours.
Just to metion the previous version of velocidrone works like a charm with it.
The new one, I think that reads the reset button in my case Aux 6, really does not think it matters as I change it sometimes.
In the midle of the game, it just stops and seens everything is reset.
I open a bug in velocidrone also to be shure.
Just open here to, if anyone is having the same issue.

If you want some information, log anything let me know please.
Thank you for such a great project!

sk8board, 2024-02-01:
I had a similar problem with the update of Velocidrone. I had to reset my controller settings in Velocidrone. When I setup my controller settings again, I found the UI would not function correctly.

I had to select the "Legacy" button on the UI to use the old controller setup UI, then I was able to get the controller settings working as I wanted. I have not had any problems since deleting my controller settings then use the legacy UI to setup my controller settings again.

eduardorcosta, 2024-02-01:
> to

I also reset the settings, the support of velocidrone recommended it.
But any of the versions of the controller setup works ok.
Is in the gameplay that the problem arises, as it seems to reset in the middle of flight
Everything stops, if I'm racing, the race stops, and the first gate is light.

sk8board, 2024-02-01:
If your controller has a USB connection, then directly connect the controller to the PC to see if the problem is still present.

If the problem is still present when directly connected using USB from the controller to the PC, then this would show their is an incompatibility between the controller and the PC or Velocidrone.

If the problem is no longer present when directly connected using USB from the controller to the PC, then this would indicate the problem is with either the receiver, CRSFJoystick software, or possibly the Waveshare RP2040-Zero.

eduardorcosta, 2024-02-01:
Yes, I tried the USB connection and it worked flawlessly.
You mention the interface, I have been trying to identify the problem, so I change buttons, remove all.
The problem is the start race button. If I mapped it as a button on the legacy interface, it has the problem, but if I mapped it as an Axis, the behaviour does not appear.
But as I said to batcave support, it did not appear in the older version of velocidrone, just this release.

sk8board, 2024-02-01:
> The problem is the start race button. If I mapped it as a button on the legacy interface, it has the problem, but if I mapped it as an Axis, the behaviour does not appear.

It seems you are stating the problem is resolved if you map to an Axis rather than a Button. If so, why don't you just use the Axis?

eduardorcosta, 2024-02-01:
Yes I changed, and it resolved. But why this only show in this version I don't know.

sk8board, 2024-02-01:
The update to Velocidrone definitely broke the Controller setup UI. I suspect there is more to this break than just the UI. Eventually the Bat Cave will get is fixed. Until then, you have a workaround that is easy to use.

eduardorcosta, 2024-02-01:
Yes!

mikeneiderhauser, 2024-11-01:
Seems like this is resolved and is a Velocidrone issue. Closing

Closed 2024-11-01.

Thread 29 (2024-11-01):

Not able to compile

ahmad-kassem, 2024-11-01:
When I compile I get the below error, please advice how to to solve that.

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

mikeneiderhauser, 2024-11-01:
Please use platformio to build the project. There should be instructions in the readme

countofkrakow, 2025-04-20:
Find updated Arduino version of this project here:

https://github.com/countofkrakow/CRSFJoystick

mikeneiderhauser, 2025-04-26:
What i'd really like to do but haven't had time to do yet is actually have github run builds and publish firmware.

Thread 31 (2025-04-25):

Not working with Aerofly RC8

ask6483, 2025-04-25:
I'm using dongle from HGLRC and can't set it up with Aerofly RC8.
Channels seem to react for a fraction of second in only one direction, attached screen recording from the setup.
In gamepad tester everything seems to be ok. I don't have this problem with Frsky XSR-Sim dongle or while using EdgeTX USB joystick.

https://github.com/user-attachments/assets/9205333f-1ece-4c81-af02-a55b6d4ba965

mikeneiderhauser, 2025-04-26:
Need to ask for a bit of additional info and list some troubleshooting steps.

1. What transmitter and what ELRS TXmodule are you using?
2. Is the ELRS TX module updated to the latest ELRS Firmware?
3. Did you reflash the HGLRC dongle with the latest pi-pico firmware for this project?
4. Did you reflash the HGLRC dongle ELRX RX module to have the latest ELRS firmware  (minimally, to match your ELRS TX)?
5. What packet rate do you have configured on your transmitter.
6. If all above are in order, can you confirm that your ELRS TX and ELRS RX module are bound?

ask6483, 2025-04-28:
1. RM Boxer Max with internal module
2. Yes everything updated
3. No it's as delivered
4. Yes it's updated to match TX
5. 100 full, 333 full
6. Yes, they are bound

I have read recently about CH5 used exclusively for arming, I will check if setting this to always on will help.

ask6483, 2025-04-28:
Ok, so I have set the CH5 to max value 100% all the time no luck, but then checked also Liftoff and I can confirm that dongle is working fine so this a problem related with how Aerofly is interacting with joystick API. Strange taht it's ignoring the channel input just after receiving first event from it.

GizmoChicken, 2025-08-10:
> Ok, so I have set the CH5 to max value 100% all the time no luck, but then checked also Liftoff and I can confirm that dongle is working fine so this a problem related with how Aerofly is interacting with joystick API. Strange that it's ignoring the channel input just after receiving first event from it.

I found following:

https://github.com/assafms/SquidTX12Emulator

The README recites:

>The original version identifies over USB as a Joystick and not as a game pad,this creates a problem with simulators as Realflight and Aerofly RC8.

I have *NOT* tested the above linked fork.   (I'm still working up the courage to do so.)

But if you have more courage than me, please post your results here.   :)

countofkrakow, 2025-08-12:
@mikeneiderhauser Sure, that works for me.

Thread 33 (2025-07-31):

error when compiling

realwarrior3, 2025-07-31:
before new update CRSFJoystick all work fine. but now I download new archive and can't compile. pls help.

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

`.pio\libdeps\waveshare2040zero\Adafruit NeoPixel\Adafruit_Neopixel_RP2.cpp: In member function 'bool Adafruit_NeoPixel::rp2040claimPIO()':
.pio\libdeps\waveshare2040zero\Adafruit NeoPixel\Adafruit_Neopixel_RP2.cpp:9:9: error: 'pio_claim_free_sm_and_add_program_for_gpio_range' was not declared in this scope
    9 |   if (! pio_claim_free_sm_and_add_program_for_gpio_range(&ws2812_program,
      |         ^~~~~~~~~~~~~~~~~~~~~~~~~~~~~~~~~~~~~~~~~~~~~~~~
.pio\libdeps\waveshare2040zero\Adafruit NeoPixel\Adafruit_Neopixel_RP2.cpp: In member function 'void Adafruit_NeoPixel::rp2040releasePIO()':
.pio\libdeps\waveshare2040zero\Adafruit NeoPixel\Adafruit_Neopixel_RP2.cpp:35:3: error: 'pio_remove_program_and_unclaim_sm' was not declared in this scope
   35 |   pio_remove_program_and_unclaim_sm(&ws2812_program, pio, pio_sm,  pio_program_offset);
      |   ^~~~~~~~~~~~~~~~~~~~~~~~~~~~~~~~~
.pio\libdeps\waveshare2040zero\Adafruit NeoPixel\Adafruit_Neopixel_RP2.cpp: In member function 'void Adafruit_NeoPixel::rp2040Show(uint8_t*, uint32_t)':
.pio\libdeps\waveshare2040zero\Adafruit NeoPixel\Adafruit_Neopixel_RP2.cpp:43:24: warning: comparison of unsigned expression < 0 is always false [-Wtype-limits]
   43 |   if (! pio || (pio_sm < 0)) {
      |                 ~~~~~~~^~~
*** [.pio\build\waveshare2040zero\libf3a\Adafruit NeoPixel\Adafruit_Neopixel_RP2.cpp.o] Error 1`

sk8board, 2025-07-31:
`[.pio\build\waveshare2040zero\libf3a\Adafruit NeoPixel\Adafruit_Neopixel_RP2.cpp.o] Error 1`

Hello Mr. Investigator,

There appears to be a problem with the neopixel library. A workaround is to comment out the library references in the `platformio.ini` file as I have shown here.

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

sk8board, 2025-07-31:
After making changes to the `platformio.ini` file, you will need to "clean" your build of the prior use of the neopixel library before rebuilding.

Sometime there is a clean button that will delete the contents in the .pio folder. If there is not such a button, then simply delete the contents in the .pio folder before you rebuild.

realwarrior3, 2025-08-01:
thx for help, but don't work :(

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

mikeneiderhauser, 2025-08-01:
You can also try it with NeoPixelConnect if you wish.

The below code builds, but is untested.  I don't have hardware on hand ATM to try this.  If you do try it and it works, i can get a fix committed to the repo to use NewPixelConnect.

Update platformio.ini to make the waveshare2040zero board look like

```
[env:waveshare2040zero]
platform = raspberrypi
board = pico
framework = arduino
lib_deps = mryslab/NeoPixelConnect@^1.4.0
build_flags = -DBOARD_ID=3
monitor_speed = 115200
```

Then modify the board_defs.h file for BOARD_ID 3 to the following

```
#if BOARD_ID == 3
    #define CRSF_TX 4
    #define CRSF_RX 5

    #define LED_TYPE LED_TYPE_NEOPIXEL
    #define LED_PIN 16

    #include <NeoPixelConnect.h>
    NeoPixelConnect p(LED_PIN, 1, pio0, 0);

    void boardSetup() {
      // noop
    }

    void led_off() {
        p.neoPixelFill(0, 0, 0, true);
    }

    void led_on() {
        p.neoPixelFill(0, 0, 255, true);
    }

    void led_color(uint8_t r, uint8_t g, uint8_t b) {
        p.neoPixelFill(r, g, b, true);
    }
#endif
```

mikeneiderhauser, 2025-08-01:
@realwarrior3  are the leds changing color appropriately and show status when bound?

Closed 2025-08-01.

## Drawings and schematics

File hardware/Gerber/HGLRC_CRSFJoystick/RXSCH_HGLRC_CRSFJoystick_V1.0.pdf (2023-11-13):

### GND

### GND

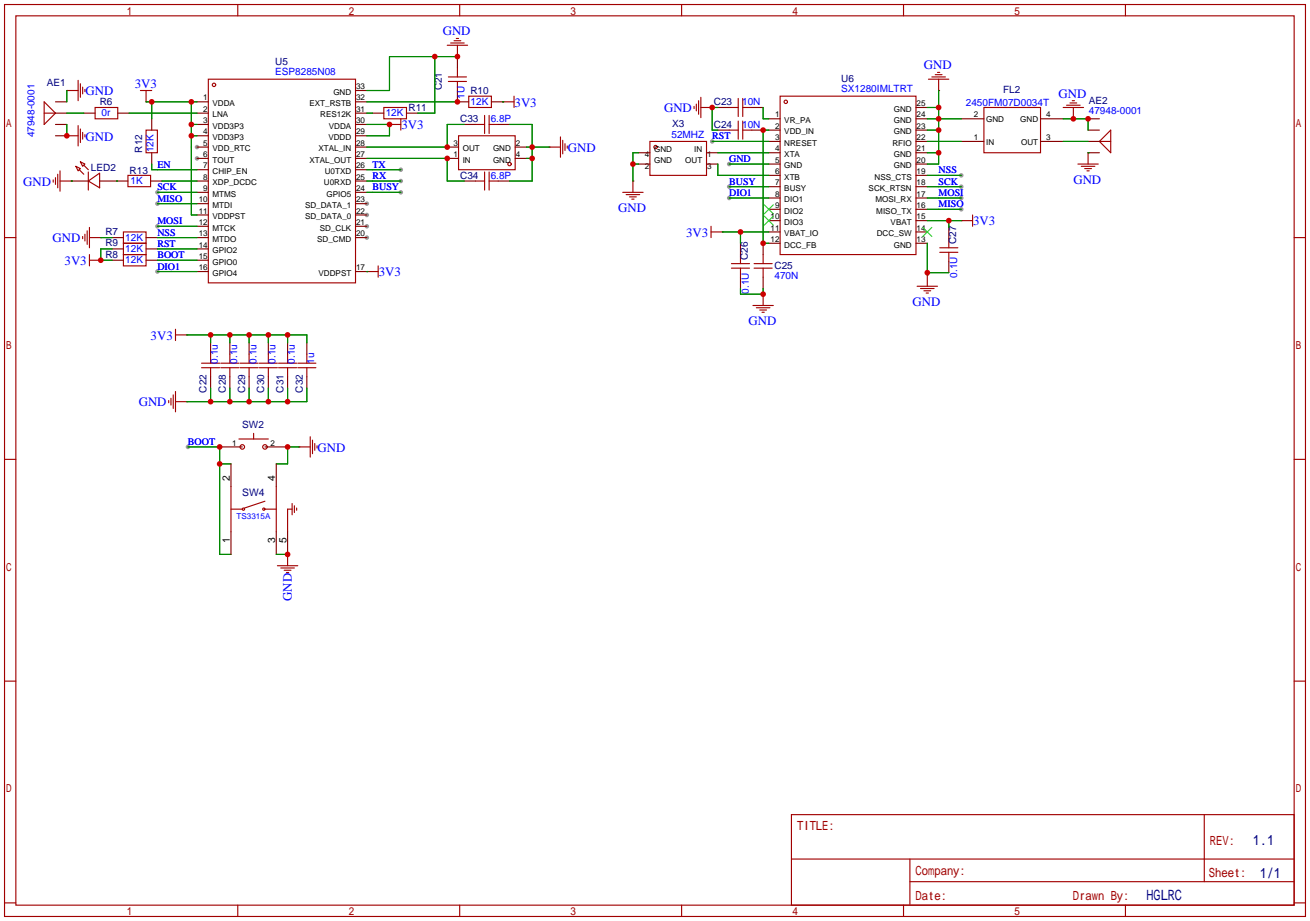
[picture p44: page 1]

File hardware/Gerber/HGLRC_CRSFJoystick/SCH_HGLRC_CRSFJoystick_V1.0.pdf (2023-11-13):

QSPI_SD3 51 | DVDD ⁵0
1.1V | 3.3V

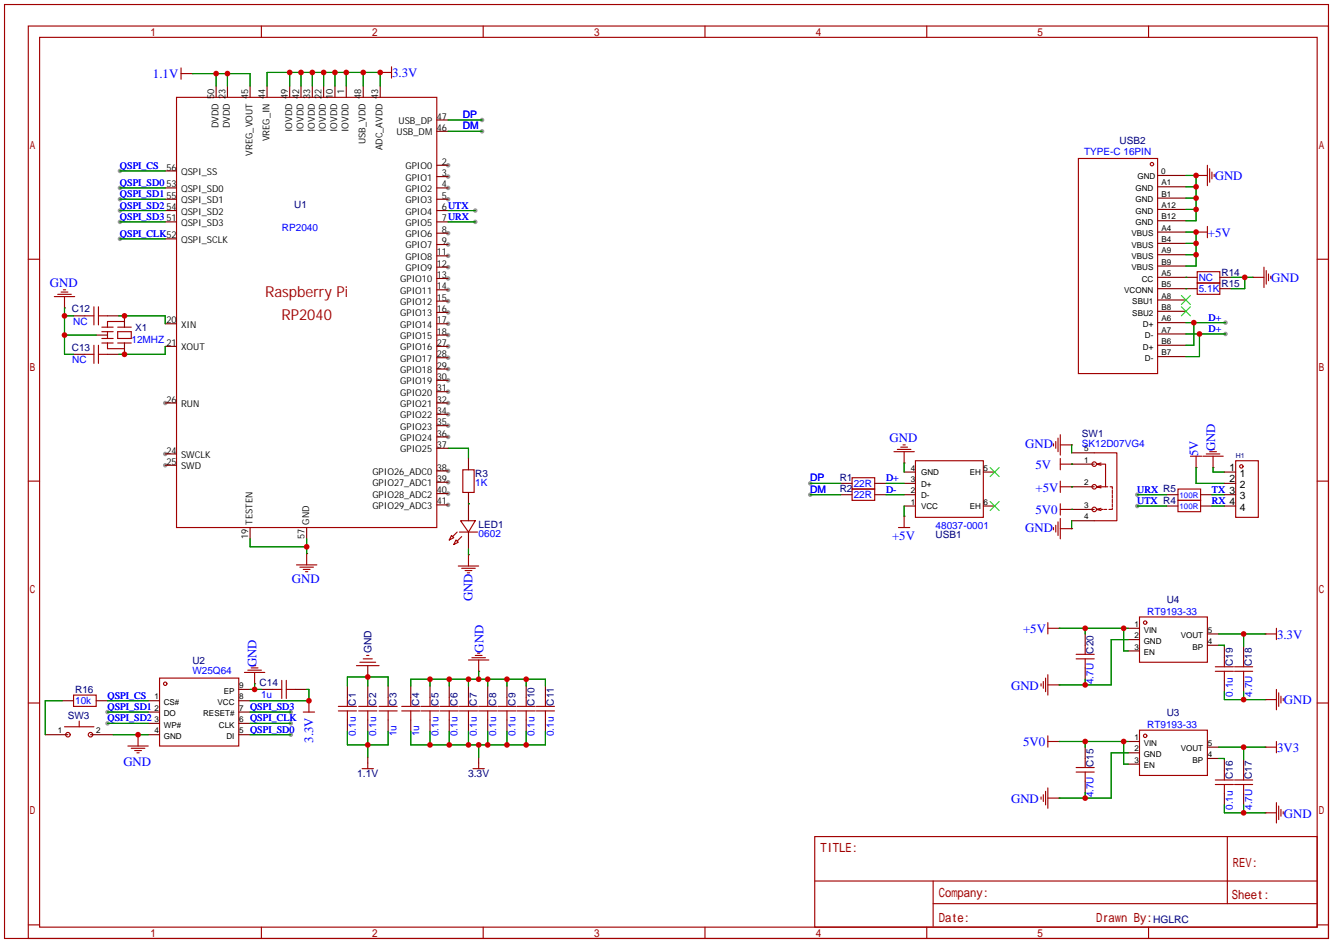
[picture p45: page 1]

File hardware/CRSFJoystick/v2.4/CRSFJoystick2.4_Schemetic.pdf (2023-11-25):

# QSPI_SD3 51 DVDD ⁵0

3V3

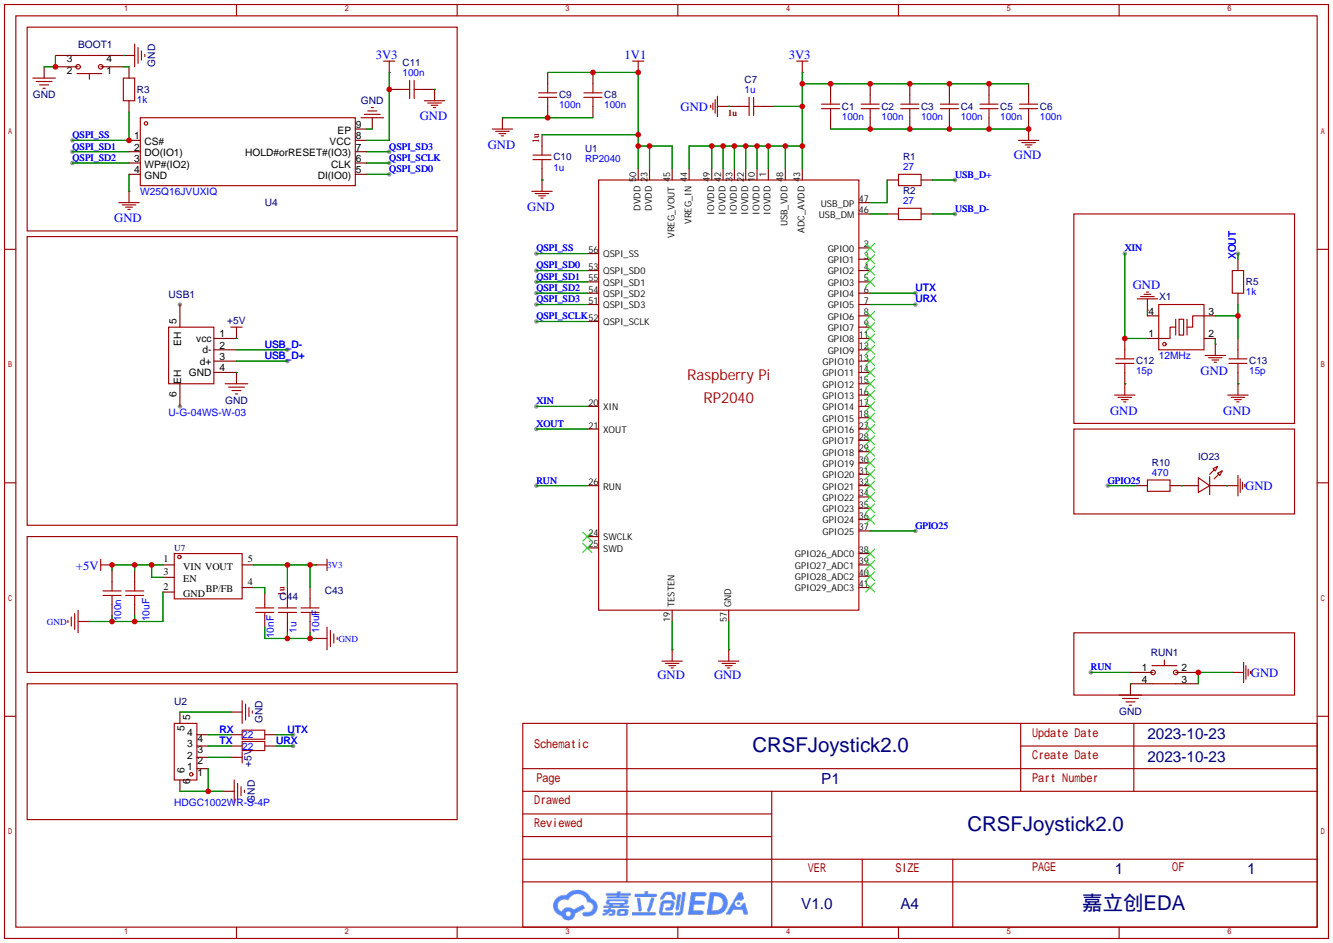
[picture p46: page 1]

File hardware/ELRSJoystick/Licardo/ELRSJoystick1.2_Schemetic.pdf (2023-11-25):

# QSPI_SD3 51 DVDD ⁵0

3V3

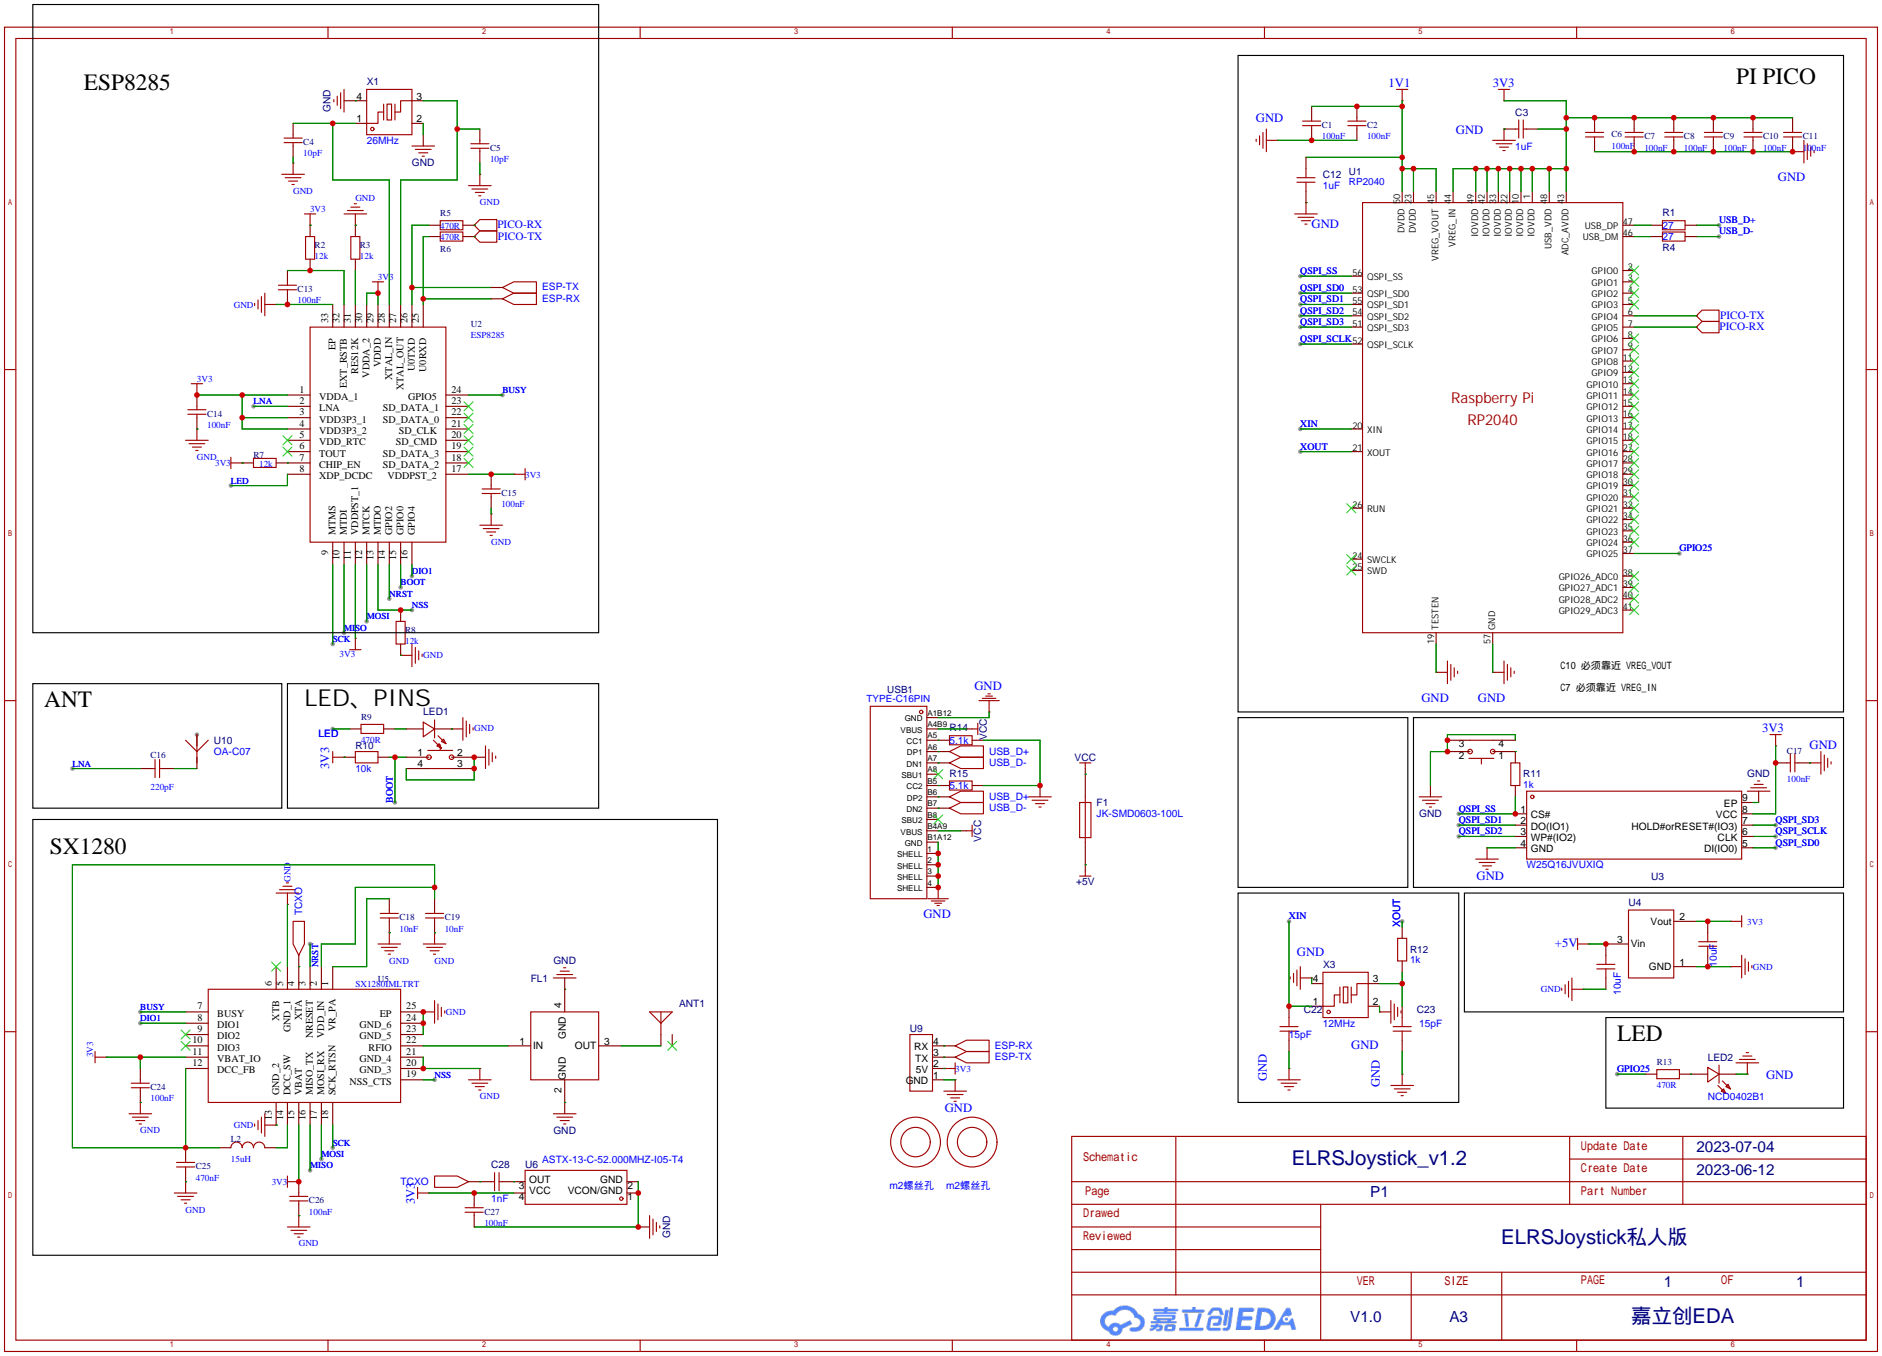
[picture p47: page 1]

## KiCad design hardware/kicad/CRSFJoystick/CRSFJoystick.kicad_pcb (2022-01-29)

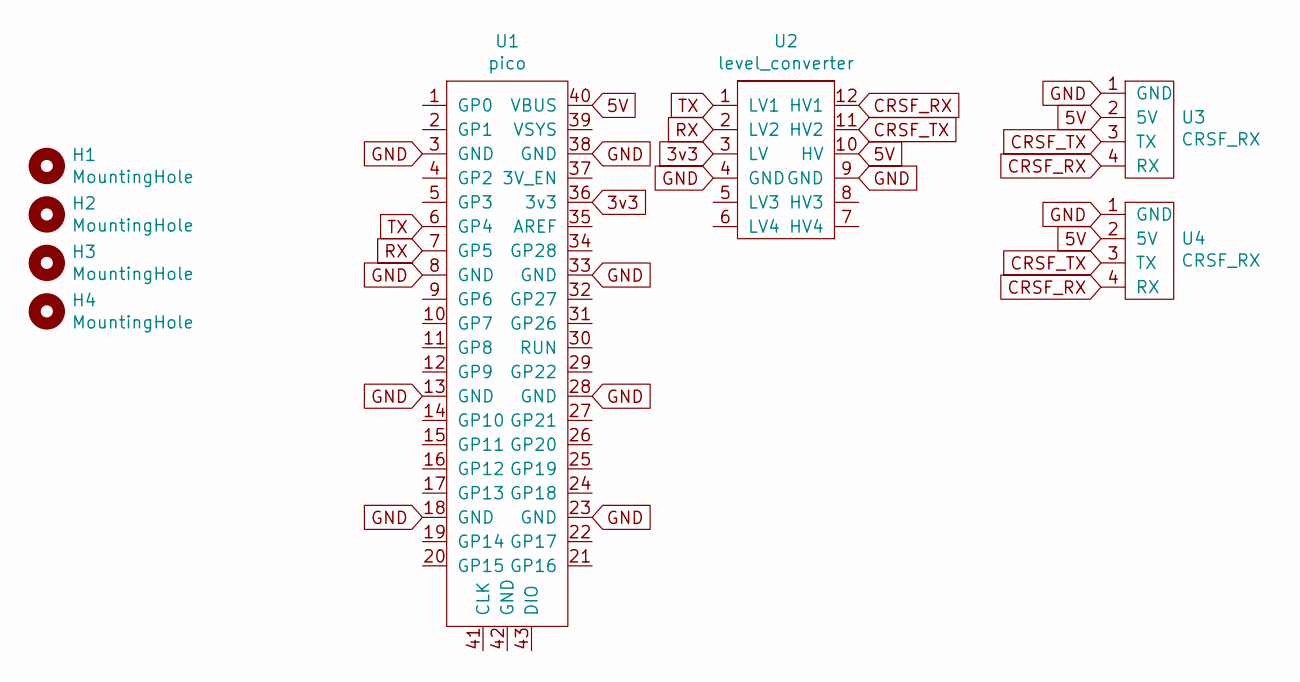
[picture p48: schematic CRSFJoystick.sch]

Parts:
H1, H2, H3, H4: MountingHole; MountingHole_2.2mm_M2
U1: pico; pico_no_swd
U2: level_converter
U3, U4: CRSF_RX; ELRS_EP2

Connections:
3v3: U1.36 (3v3), U2.3 (LV)
5V: U1.40 (VBUS), U2.10 (HV), U3.2 (5V), U4.2 (5V)
CRSF_RX: U2.12 (HV1), U3.4 (RX), U4.4 (RX)
CRSF_TX: U2.11 (HV2), U3.3 (TX), U4.3 (TX)
GND: U1.3 (GND), U1.8 (GND), U1.13 (GND), U1.18 (GND), U1.23 (GND), U1.28 (GND), U1.33 (GND), U1.38 (GND), U2.4 (GND), U2.9 (GND), U3.1 (GND), U4.1 (GND)
RX: U1.7 (GP5), U2.2 (LV2)
TX: U1.6 (GP4), U2.1 (LV1)

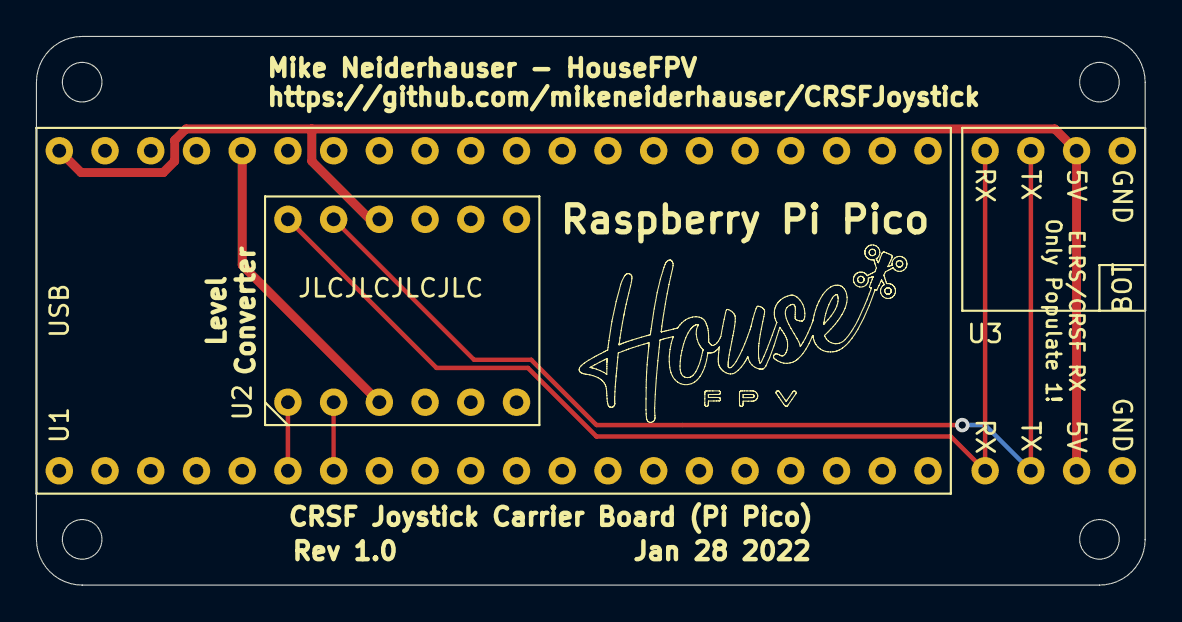
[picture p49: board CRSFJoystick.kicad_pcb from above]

Board: 2 copper layers, 61.6 x 30.5 mm, 8 parts (1 on the bottom side), 7 nets.

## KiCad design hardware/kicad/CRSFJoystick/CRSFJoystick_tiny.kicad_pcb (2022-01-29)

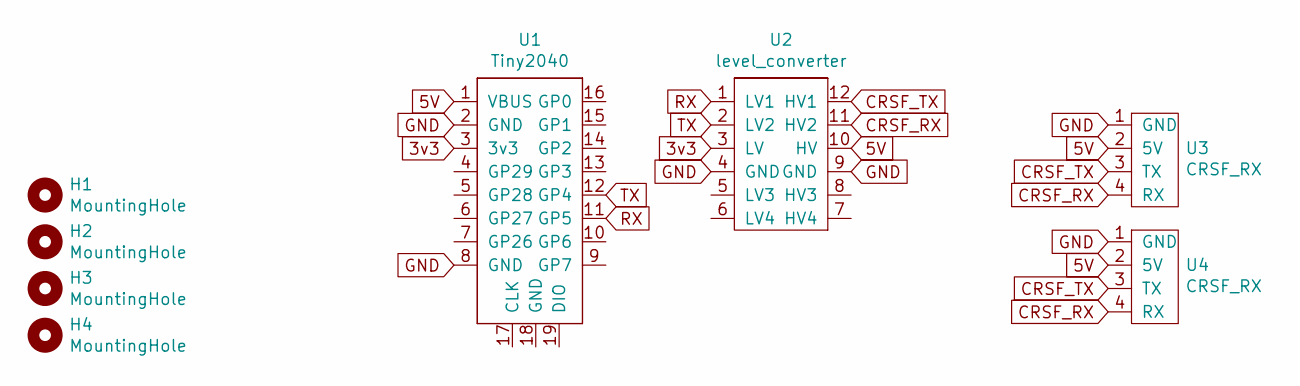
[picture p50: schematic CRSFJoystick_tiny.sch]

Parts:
H1, H2, H3, H4: MountingHole; MountingHole_2.2mm_M2
U1: Tiny2040; tiny2040_no_swd
U2: level_converter
U3, U4: CRSF_RX; ELRS_EP2

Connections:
3v3: U1.3 (3v3), U2.3 (LV)
5V: U1.1 (VBUS), U2.10 (HV), U3.2 (5V), U4.2 (5V)
CRSF_RX: U2.11 (HV2), U3.4 (RX), U4.4 (RX)
CRSF_TX: U2.12 (HV1), U3.3 (TX), U4.3 (TX)
GND: U1.2 (GND), U1.8 (GND), U2.4 (GND), U2.9 (GND), U3.1 (GND), U4.1 (GND)
RX: U1.11 (GP5), U2.1 (LV1)
TX: U1.12 (GP4), U2.2 (LV2)

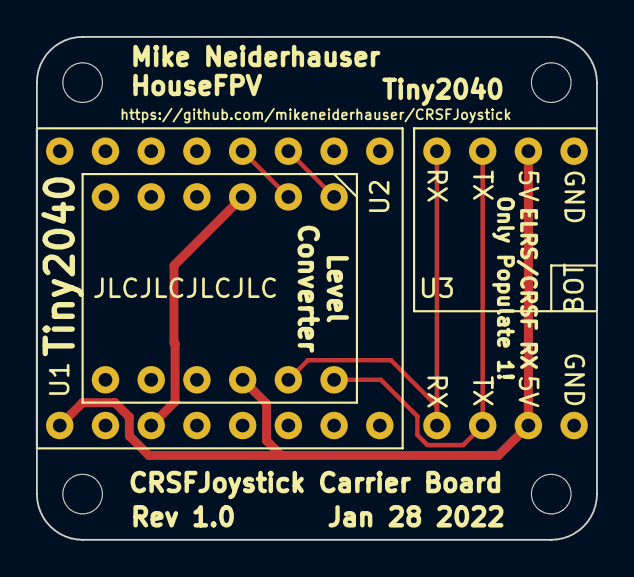
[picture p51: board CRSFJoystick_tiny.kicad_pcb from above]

Board: 2 copper layers, 31.1 x 27.9 mm, 8 parts (1 on the bottom side), 7 nets.

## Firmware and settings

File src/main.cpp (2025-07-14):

#include <Arduino.h>
#include <CrsfSerial.h>  // https://github.com/CapnBry/CRServoF/
#include <PicoGamepad.h> // https://gitlab.com/realrobots/PicoGamepad/-/tree/master

#include "calibration.h"

// BOARD_ID SELECTION HAPPENS IN PLATFORMIO ENVIRONMENT SELECTION

// Blink routine variables and state tracking
#define BLINK_ENABLED                    // comment this line out to disable led blink
#define BLINK_TIME 60000                 // blink routine window (in ms)
#define BLINK_DELAY 500                  // delay in between led state change (in ms)

static bool serialEcho;
static char serialInBuff[64];
static uint8_t serialInBuffLen;

bool led_state = false;                  // track led on/off state
unsigned long ms_curr = 0;               // current time
unsigned long ms_last_link_changed = 0;  // last time crsf link changed
unsigned long ms_last_led_changed = 0;   // last time led changed state in blink routine

#include "board_defs.h"

UART Serial2(CRSF_TX, CRSF_RX, NC, NC);

CrsfSerial crsf(Serial2, CRSF_BAUDRATE); // pass any HardwareSerial port
int channel_data = 0;
int map_data = 0;

PicoGamepad gamepad;

btn_config *c;

/***
 * This callback is called whenever new channel values are available.
 * Use crsf.getChannel(x) to get us channel values (1-16).
 ***/
void packetChannels()
{
    // Manually expanding instead of looping so I can change params as needed

    // X - Channel 1 - A
    channel_data = crsf.getChannel(1);
    map_data = map(channel_data, \
      CHANNEL_1_LOW_EP,          \
      CHANNEL_1_HIGH_EP,         \
      JOYSTICK_LOW,              \
      JOYSTICK_HIGH);
    gamepad.SetX(map_data);

    // Y - Channel 2 - E
    channel_data = crsf.getChannel(2);
    map_data = map(channel_data, \
      CHANNEL_2_LOW_EP,          \
      CHANNEL_2_HIGH_EP,         \
      JOYSTICK_LOW,              \
      JOYSTICK_HIGH);
    gamepad.SetY(map_data);

    // Rx - Channel 3 - T
    channel_data = crsf.getChannel(3);
    map_data = map(channel_data, \
      CHANNEL_3_LOW_EP,          \
      CHANNEL_3_HIGH_EP,         \
      JOYSTICK_LOW,              \
      JOYSTICK_HIGH);
    gamepad.SetRx(map_data);

    // Ry - Channel 4 - R
    channel_data = crsf.getChannel(4);
    map_data = map(channel_data, \
      CHANNEL_4_LOW_EP,          \
      CHANNEL_4_HIGH_EP,         \
      JOYSTICK_LOW,              \
      JOYSTICK_HIGH);
    gamepad.SetRy(map_data);

    // Z - Channel 5
    channel_data = crsf.getChannel(5);
    map_data = map(channel_data, \
      CHANNEL_5_LOW_EP,          \
      CHANNEL_5_HIGH_EP,         \
      JOYSTICK_LOW,              \
      JOYSTICK_HIGH);
    gamepad.SetZ(map_data);

    // Rz - Channel 6
    channel_data = crsf.getChannel(6);
    map_data = map(channel_data, \
      CHANNEL_6_LOW_EP,          \
      CHANNEL_6_HIGH_EP,         \
      JOYSTICK_LOW,              \
      JOYSTICK_HIGH);
    gamepad.SetRz(map_data);

    // Rx - Channel 7
    channel_data = crsf.getChannel(7);
    map_data = map(channel_data, \
      CHANNEL_7_LOW_EP,          \
      CHANNEL_7_HIGH_EP,         \
      JOYSTICK_LOW,              \
      JOYSTICK_HIGH);
    gamepad.SetThrottle(map_data);

    // Rx - Channel 8
    channel_data = crsf.getChannel(8);
    map_data = map(channel_data, \
      CHANNEL_8_LOW_EP,          \
      CHANNEL_8_HIGH_EP,         \
      JOYSTICK_LOW,              \
      JOYSTICK_HIGH);
    gamepad.SetS0(map_data);

    // Ry - unused
    // gamepad.SetRy(map_data);
    // Rz - unused
    // gamepad.SetRz(map_data);
    // S0 - unused
    // gamepad.SetS0(map_data);

    // Multi-position switches can be set up in calibrations.h
    // The button will report HIGH when the channel is withing
    // a lower / upper bound (inclusive) constraint.
    // Default is HIGH (1510, 2011) else LOW

    for(uint8_t i = 0; i < NUM_BUTTONS; i++){
      c = &btn_map[i];
      channel_data = crsf.getChannel(c->channel);
      // bounds check inclusive
      if(channel_data >= c->lower_bound && channel_data <= c->upper_bound) {
        map_data = c->invert ? LOW : HIGH;
      }
      else {
        map_data = c->invert ? HIGH : LOW;
      }
      gamepad.SetButton(c->id, map_data);

      #ifdef BTN_PRINT
      Serial.print("b: "); Serial.print(c->id));
      Serial.print(" c: "); Serial.print(channel_data);
      Serial.print(" m: "); Serial.println(map_data);
      #endif
    }
    // TODO what to do with Channel 13,14,15,16 (NA,NA,LQ,RSSI)

    // Set hat direction, 4 hats available. direction is clockwise 0=N 1=NE 2=E 3=SE 4=S 5=SW 6=W 7=NW 8=CENTER
    // gamepad.SetHat(0, 8);

    gamepad.send_update();
}

void crsfLinkUp() {
  ms_last_link_changed = millis();
  ms_last_led_changed = ms_last_link_changed;
  led_state = true;
  led_on();
}

void crsfLinkDown() {
  ms_last_link_changed = millis();
  ms_last_led_changed = ms_last_link_changed;
  led_state = false;
  led_off();
}

static void passthroughBegin(uint32_t baud)
{
    if (baud != crsf.getBaud())
    {
        // Force a reboot command since we want to send the reboot
        // at 420000 then switch to what the user wanted
        const uint8_t rebootpayload[] = { 'b', 'l' };
        crsf.queuePacket(CRSF_ADDRESS_CRSF_RECEIVER, CRSF_FRAMETYPE_COMMAND, &rebootpayload, sizeof(rebootpayload));
    }
    crsf.setPassthroughMode(true, baud);

    serialEcho = false;
}

static void crsfOobData(uint8_t b)
{
    Serial.write(b);
}

/***
 * @brief Processes a text command like we're some sort of CLI or something
 * @return true if CrsfSerial was placed into passthrough mode, false otherwise
*/
static bool handleSerialCommand(char *cmd)
{
    // Fake a CRSF RX on UART6
    bool prompt = true;
    if (strcmp(cmd, "#") == 0)
    {
        Serial.println("Fake CLI Mode, type 'exit' or 'help' to do nothing\r\n");
        serialEcho = true;
    }

    else if (strcmp(cmd, "serial") == 0)
        Serial.println("serial 5 64 0 0 0 0\r\n");

    else if (strcmp(cmd, "get serialrx_provider") == 0)
        Serial.println("serialrx_provider = CRSF\r\n");

    else if (strcmp(cmd, "get serialrx_inverted") == 0)
        Serial.println("serialrx_inverted = OFF\r\n");

    else if (strcmp(cmd, "get serialrx_halfduplex") == 0)
        Serial.println("serialrx_halfduplex = OFF\r\n");

    else if (strncmp(cmd, "serialpassthrough 5 ", 20) == 0)
    {
        Serial.println(cmd);

        unsigned int baud = atoi(&cmd[20]);
        passthroughBegin(baud);

        return true;
    }

    else
        prompt = false;

    if (prompt)
        Serial.print("# ");

    return false;
}

static void checkSerialInNormal()
{
    while (Serial.available())
    {
        char c = Serial.read();
        if (serialEcho && c != '\n')
            Serial.write(c);

        if (c == '\r' || c == '\n')
        {
            if (serialInBuffLen != 0)
            {
                Serial.write('\n');
                serialInBuff[serialInBuffLen] = '\0';
                serialInBuffLen = 0;

                bool goToPassthrough = handleSerialCommand(serialInBuff);
                // If need to go to passthrough, get outta here before we dequeue any bytes
                if (goToPassthrough)
                    return;
            }
        }
        // Betaflight CLI is entered just by hitting #, no return needed
        else if (c == '#')
        {
            serialInBuffLen = 0;
            handleSerialCommand("#");
        }
        else
        {
            serialInBuff[serialInBuffLen++] = c;
            // if the buffer fills without getting a newline, just reset
            if (serialInBuffLen >= sizeof(serialInBuff))
                serialInBuffLen = 0;
        }
    }  /* while Serial */
}

static void checkSerialInPassthrough()
{
    static uint32_t lastData = 0;
    static bool LED = false;
    bool gotData = false;
    unsigned int avail;
    while ((avail = Serial.available()) != 0)
    {
        uint8_t buf[16];
        avail = Serial.readBytes((char *)buf, min(sizeof(buf), avail));
        crsf.write(buf, avail);
        LED ? led_on() : led_off();
        LED = !LED;
        gotData = true;
    }
    // If longer than X seconds since last data, switch out of passthrough
    if (gotData || !lastData)
        lastData = millis();

    // Turn off LED 1s after last data
    else if (LED && (millis() - lastData > 1000))
    {
        LED = false;
        led_off();
    }

    // Short blink LED after timeout
    else if (millis() - lastData > 5000)
    {
        lastData = 0;
        led_on();
        delay(200);
        led_off();
        crsf.setPassthroughMode(false);
    }
}

static void checkSerialIn()
{
    if (crsf.getPassthroughMode())
        checkSerialInPassthrough();
    else
        checkSerialInNormal();
}

#ifdef BLINK_ENABLED
void led_loop() {
  ms_curr = millis();
  // link is down
  if(!crsf.isLinkUp()) {
    // within the blink routine window (BLINK_TIME)
    if(ms_curr < (ms_last_link_changed + BLINK_TIME)) {
      // handle led toggle delay
      if(ms_curr > (ms_last_led_changed + BLINK_DELAY)) {
        ms_last_led_changed = ms_curr;
        led_state ? led_on() : led_off();
        led_state = !led_state;  // toggle led state
      }
    }
    else
    {
      // ensure the led is off if the blink routine expired and link is down
      led_off();
    }
  }
}
#endif

void setup()
{
    Serial.begin(115200);
    boardSetup();
    crsfLinkDown();

    gamepad.send_update();

    // Attach the channels callback
    crsf.onPacketChannels = &packetChannels;
    crsf.onLinkUp = &crsfLinkUp;
    crsf.onLinkDown = &crsfLinkDown;
    crsf.onOobData = &crsfOobData;
    crsf.begin();
    serialEcho = true;
}

void loop()
{
    // Must call CrsfSerial.loop() in loop() to process data
    crsf.loop();
    checkSerialIn();
    #ifdef BLINK_ENABLED
    led_loop();
    #endif
}

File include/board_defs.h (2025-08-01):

#ifndef BOARD_DEFS
#define BOARD_DEFS

#define LED_TYPE_SINGLE 1
#define LED_TYPE_NEOPIXEL 2
#define LED_TYPE_RGB 3

// Raspberry Pi Pico
#if BOARD_ID == 1
    #define CRSF_TX 4  // physical 6
    #define CRSF_RX 5  // physical 7

    #define LED_TYPE LED_TYPE_SINGLE
    #define LED_PIN 25
    
    void boardSetup() {
      pinMode(LED_PIN, OUTPUT);
    }

    void led_off() {
      digitalWrite(LED_PIN, LOW);
    }
    
    void led_on() {
      digitalWrite(LED_PIN, HIGH);
    }
#endif

// Pimoroni Tiny 2040
#if BOARD_ID == 2
    #define CRSF_TX 4
    #define CRSF_RX 5

    #define LED_TYPE LED_TYPE_RGB
    #define LED_PIN_R 18
    #define LED_PIN_G 19
    #define LED_PIN_B 20
    
    void boardSetup() {
      pinMode(LED_PIN_R, OUTPUT);
      pinMode(LED_PIN_G, OUTPUT);
      pinMode(LED_PIN_B, OUTPUT);
    }

    void led_off() {
      digitalWrite(LED_PIN_R, HIGH);
      digitalWrite(LED_PIN_G, HIGH);
      digitalWrite(LED_PIN_B, HIGH);
    }
    
    void led_on() {
      digitalWrite(LED_PIN_R, HIGH);
      digitalWrite(LED_PIN_G, HIGH);
      digitalWrite(LED_PIN_B, LOW);
    }
#endif

// WaveShare RP2040 Zero
#if BOARD_ID == 3
    #define CRSF_TX 4
    #define CRSF_RX 5

    #define LED_TYPE LED_TYPE_NEOPIXEL
    #define LED_PIN 16

    #include <NeoPixelConnect.h>
    NeoPixelConnect p(LED_PIN, 1, pio0, 0);
    
    void boardSetup() {
      // noop
    }

    void led_off() {
        p.neoPixelFill(0, 0, 0, true);
    }
    
    void led_on() {
        p.neoPixelFill(0, 0, 255, true);
    }

    void led_color(uint8_t r, uint8_t g, uint8_t b) {
        p.neoPixelFill(r, g, b, true);
    }
#endif

// Seeed XIAO RP2040
#if BOARD_ID == 4
    #define CRSF_TX 0
    #define CRSF_RX 1

    // 1 NEOPixel - currently unused
    #define LED_TYPE LED_TYPE_NEOPIXEL
    #define LED_NEO_PWR 11
    #define LED_PIN 12

    #include <NeoPixelConnect.h>
    NeoPixelConnect p(LED_PIN, 1, pio0, 0);
    
    // 1 Active Low RGB
    //#define LED_ACTIVE_LOW LED_ACTIVE_LOW_TRUE
    //#define LED_TYPE LED_TYPE_RGB
    #define LED_PIN_R 17
    #define LED_PIN_G 16
    #define LED_PIN_B 25

    void boardSetup() {
        // Enable neopixel LED
        pinMode(LED_NEO_PWR, OUTPUT);
        digitalWrite(LED_NEO_PWR, HIGH);
        // Turn off user led
        pinMode(LED_PIN_R, OUTPUT);
        pinMode(LED_PIN_G, OUTPUT);
        pinMode(LED_PIN_B, OUTPUT);
        digitalWrite(LED_PIN_R, HIGH);
        digitalWrite(LED_PIN_G, HIGH);
        digitalWrite(LED_PIN_B, HIGH);
    }

    void led_off() {
        p.neoPixelFill(0, 0, 0, true);
    }
    
    void led_on() {
        p.neoPixelFill(0, 0, 255, true);
    }

    void led_color(uint8_t r, uint8_t g, uint8_t b) {
        p.neoPixelFill(r, g, b, true);
    }
#endif

// Adafruit QT Py RP2040
#if BOARD_ID == 5
    #define CRSF_TX 20
    #define CRSF_RX 5

    // 1 NEOPixel
    #define LED_TYPE LED_TYPE_NEOPIXEL
    #define LED_NEO_PWR 11
    #define LED_PIN 12

    #include <NeoPixelConnect.h>
    NeoPixelConnect p(LED_PIN, 1, pio0, 0);

    void boardSetup() {
        pinMode(LED_NEO_PWR, OUTPUT);
        digitalWrite(LED_NEO_PWR, HIGH);
    }

    void led_off() {
        p.neoPixelFill(0, 0, 0, true);
    }
    
    void led_on() {
        p.neoPixelFill(0, 0, 255, true);
    }

    void led_color(uint8_t r, uint8_t g, uint8_t b) {
        p.neoPixelFill(r, g, b, true);
    }
#endif

#endif

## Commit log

2022-01-21 Add ability to map aux ranges to buttons. Multi position support
2022-01-21 Add Demo vid. Configurable buttons
2022-01-29 Add kicad project files and gerber files
    [CRSFJoystick.kicad_pcb, CRSFJoystick.sch, CRSFJoystick_tiny.kicad_pcb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]
2022-01-29 Add proto carrier boards to README
2022-03-14 add stl files for enclosures
    [Lower.stl, Pico Lower.stl, pico top.stl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]
2022-03-14 changes to readme adding prints and level shifter pictures
2022-04-02 Add UART define for SEEED XIAO board
2022-04-12 Add LED Libs
2022-04-12 Code changes for board specific LED changes
2022-05-02 Add gerber files for R1.1 that removes level converter
2022-05-08 Add XIAO RP2040 board
2022-05-23 changes to readme adding prints and pictures for Waveshare 2040
    [Waveshare PR2040 top.stl, Waveshare RP2040 Lower.stl]
2022-06-04 Defaulting to Waveshare board. Removing typo in setup
2022-11-29 2.0 version 1. A new usb version hardware. 2. Update all libraries to the latest version.
    [CRSFJoystick2.0_Base.stl, CRSFJoystick2.0_Top.stl]
2022-11-29 add bom file
2022-11-30 fixed a bom error
2023-10-18 Add schematic file
2023-10-22 Rework repository to work with PlatformIO
    [board_defs.h, calibration.h, main.cpp]
2023-10-23 add schematic of CRSFJoystick2.0 and ELRSJoystick
    [Bottom.STL, Button.stl, CRSFJoystick2.0_Base.stl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]
2023-10-23 rename folder
    [Bottom.STL, Cover.STL, Lower.stl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]
2023-10-23 reorder folders
    [Waveshare PR2040 top.stl, Waveshare RP2040 Lower.stl]
2023-10-24 Add files via upload
    Add receiver schematic
2023-11-25 Add pin reference table for Pi Pico
2023-12-03 make the hole bigger to meet JLC's free policy
2024-02-03 Add support for Adafruit QT Py RP2040 board.
2025-05-16 Betaflight's CLI only requires hash, not CRLF so recent ELRS upload doesn't work
    [main.cpp]
